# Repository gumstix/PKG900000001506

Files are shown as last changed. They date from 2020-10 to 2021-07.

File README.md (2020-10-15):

# Gumstix Raspberry Pi CM Robo
## PKG900000001506 

**The Gumstix Raspberry Pi CM Robo** carrier board is a slim, computer vision-capable multimedia platform designed with miniature autonomous vehicles in mind.  The dual Raspberry Pi Camera connectors can provide either stereoscopic depth mapping for object avoidance or front- and back-facing cameras for feature identification or manual control.

I2C and UART serial connections, exposed via JST GH-style headers, can be used to connect either to PWM motor controller boards, or to a control MCU.

Instantly upgrade your project with the Gumstix Raspberry Pi CM4 Uprev board and take advantage of the CM4's increased horsepower.  Or go even further with the UprevAI and add a Google Coral TPU for lightning-fast TensorFlow processing.

__Features Include__:
* Power via **USB Type-C Power Delivery**
* Mini-HDMI-out
* DSI touch display connector
* Dual CSI2 camera connectors
* USB Type-A host connection
* 2x WS2812B-MINI RGB LEDs

__Links:__
* [AutoDoc Datasheet][autodoc]
* [Specifications][spec]
* [Store Page][store]
* [Schematics and Layout][hardware]

[thumbnail]: https://d3iwea566ns1n1.cloudfront.net/images/product/cfc476a8175b0227c75bd2853a3e6107ad4b8505.png
[autodoc]: PKG900000001506_AutoDoc.pdf
[spec]: PKG900000001506_SpecSheet.pdf
[store]: https://store.gumstix.com/cm-robo/
[hardware]: hardware/hardware.md
[firmware]: firmware/firmware.md

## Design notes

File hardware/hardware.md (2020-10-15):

# Hardware

[Schematic PDF][pdf]
EAGLE [Schematic][sch] and [Layout][brd]

[pdf]: PKG900000001506.pdf
[brd]: PKG900000001506.brd
[sch]: PKG900000001506.sch

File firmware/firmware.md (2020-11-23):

# Firmware

__Custom Gumstix Ubuntu Server 20.04 images for Rasberry Pi CM4__:

* [Ubuntu Server 20.04](https://gumstix-ubuntu.s3-us-west-2.amazonaws.com/2020-10-18/raspberrypi-cm4/rosbuntu_cm4_i2.img.gz)
* Username: ubuntu
* Password: raspberry

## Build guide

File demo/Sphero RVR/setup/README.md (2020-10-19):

# Demo

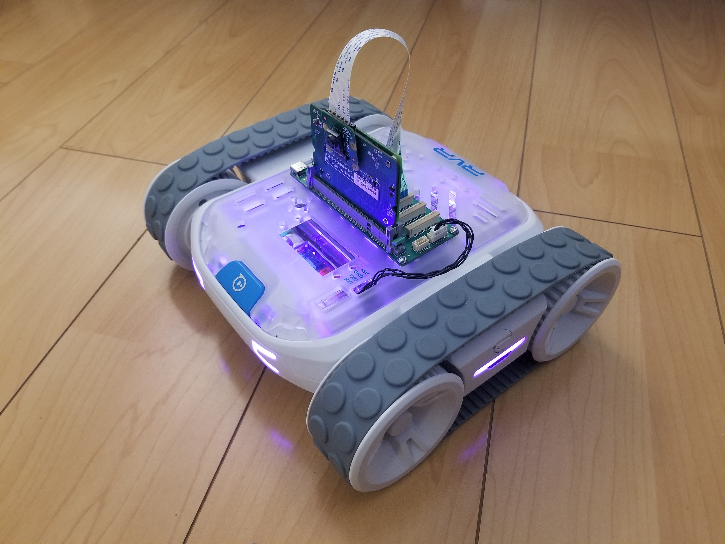
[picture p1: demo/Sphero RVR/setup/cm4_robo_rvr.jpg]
Gumstix Raspberry Pi CM4 Robo (https://youtu.be/AIH_TkKFwOI "Gumstix Raspberry Pi CM4 Robo")


# Demo

v4l2loopback Installation

    git clone https://github.com/umlaeute/v4l2loopback
    cd v4l2loopback
    make && sudo make install && sudo depmod -a

Sphero-sdk Installation

    git clone https://github.com/sphero-inc/sphero-sdk-raspberrypi-python
    cd sphero-sdk-raspberrypi-python
    sudo python3 setup.py install

Map ttyS0 to UART4
* Remove all console references in /boot/firmware/cmdline.txt
* Remove “enable_uart = 1” in /boot/firmware/syscfg.txt
* Add “dtoverlay = uart4” in /boot/firmware/usercfg.txt
* Write to /etc/rc.local:

    ~~~
    #!/bin/bash
    ln -s /dev/ttyAMA1 /dev/ttyS0
    ~~~

*       sudo chmod a+x /etc/rc.local

ROS2 Foxy Installation

    sudo apt update && sudo apt install curl gnupg2 lsb-release
    curl -s https://raw.githubusercontent.com/ros/rosdistro/master/ros.asc | sudo apt-key add –
    sudo sh -c 'echo "deb [arch=$(dpkg --print-architecture)] http://packages.ros.org/ros2/ubuntu $(lsb_release -cs) main" > /etc/apt/sources.list.d/ros2-latest.list'
    sudo apt update
    sudo apt install ros-foxy-ros-base
    echo "source /opt/ros/foxy/setup.sh" >> ~/.bashrc

Remotv installation

    git clone https://github.com/remotv/controller.git remotv
    cd remotv/
    sudo apt install ffmpeg python3-serial python3-dev libgnutls28-dev espeak python3-smbus python3-pip git
    wget https://raw.githubusercontent.com/Yoruio/controller/master/hardware/rvrros.py -O hardware/rvrros.py
    cp controller.sample.conf controller.conf

edit controller.conf (https://github.com/remotv/controller -> ‘Configure the controller’)

Opencv Streamer

    sudo apt-get install libopencv-dev python3-opencv
    sudo apt-get install libgstreamer1.0-0 gstreamer1.0-plugins-base gstreamer1.0-plugins-good \
    gstreamer1.0-plugins-bad gstreamer1.0-plugins-ugly gstreamer1.0-libav gstreamer1.0-doc \
    gstreamer1.0-tools gstreamer1.0-x gstreamer1.0-alsa gstreamer1.0-gl gstreamer1.0-gtk3 gstreamer1.0- \
    qt5 gstreamer1.0-pulseaudio
    git clone https://github.com/yoruio/coral-streamer

ROS RVR Node installation

    git clone https://github.com/Yoruio/ros2-rvr-node (run synchronous.py)

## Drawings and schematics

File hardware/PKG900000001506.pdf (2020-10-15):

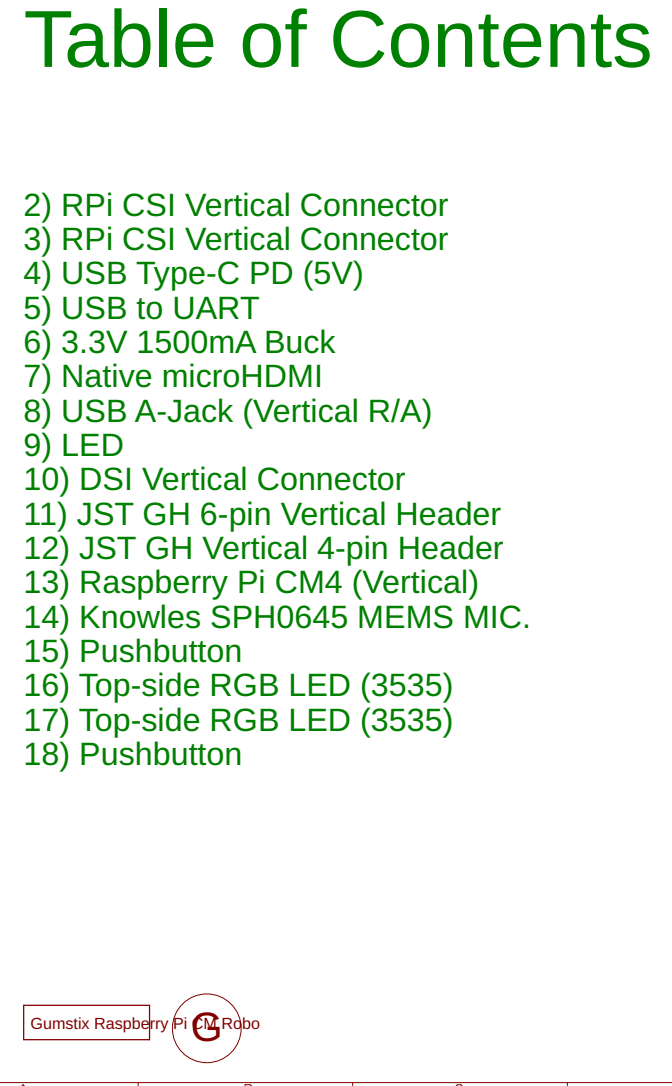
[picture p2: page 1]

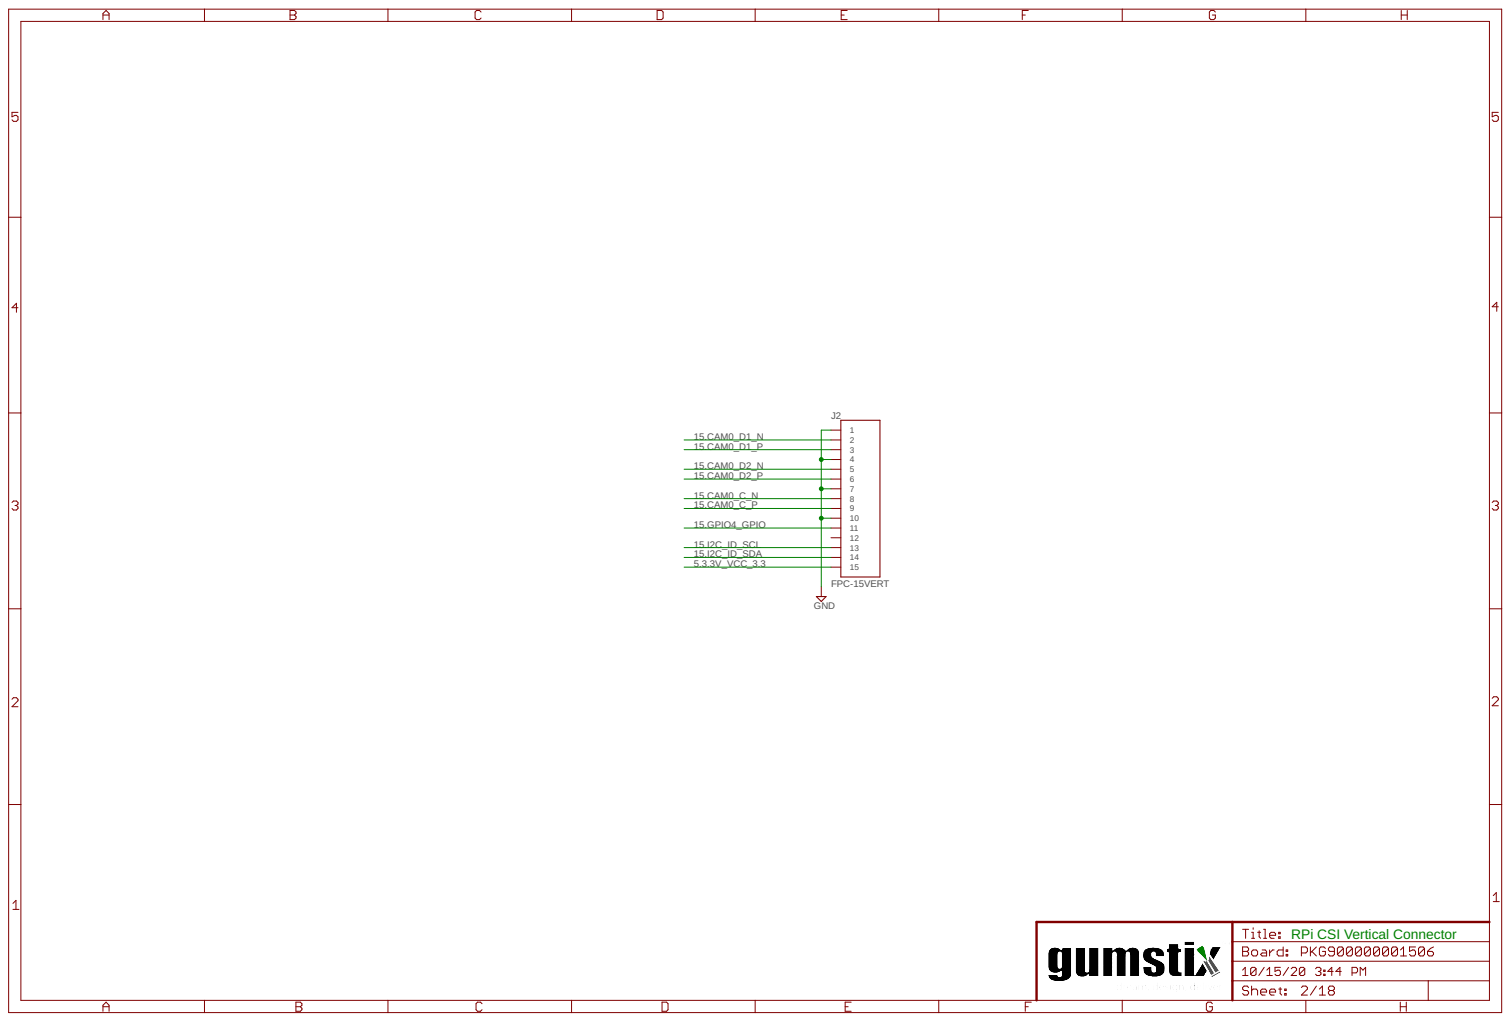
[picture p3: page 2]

RPi CSI Vertical Connector

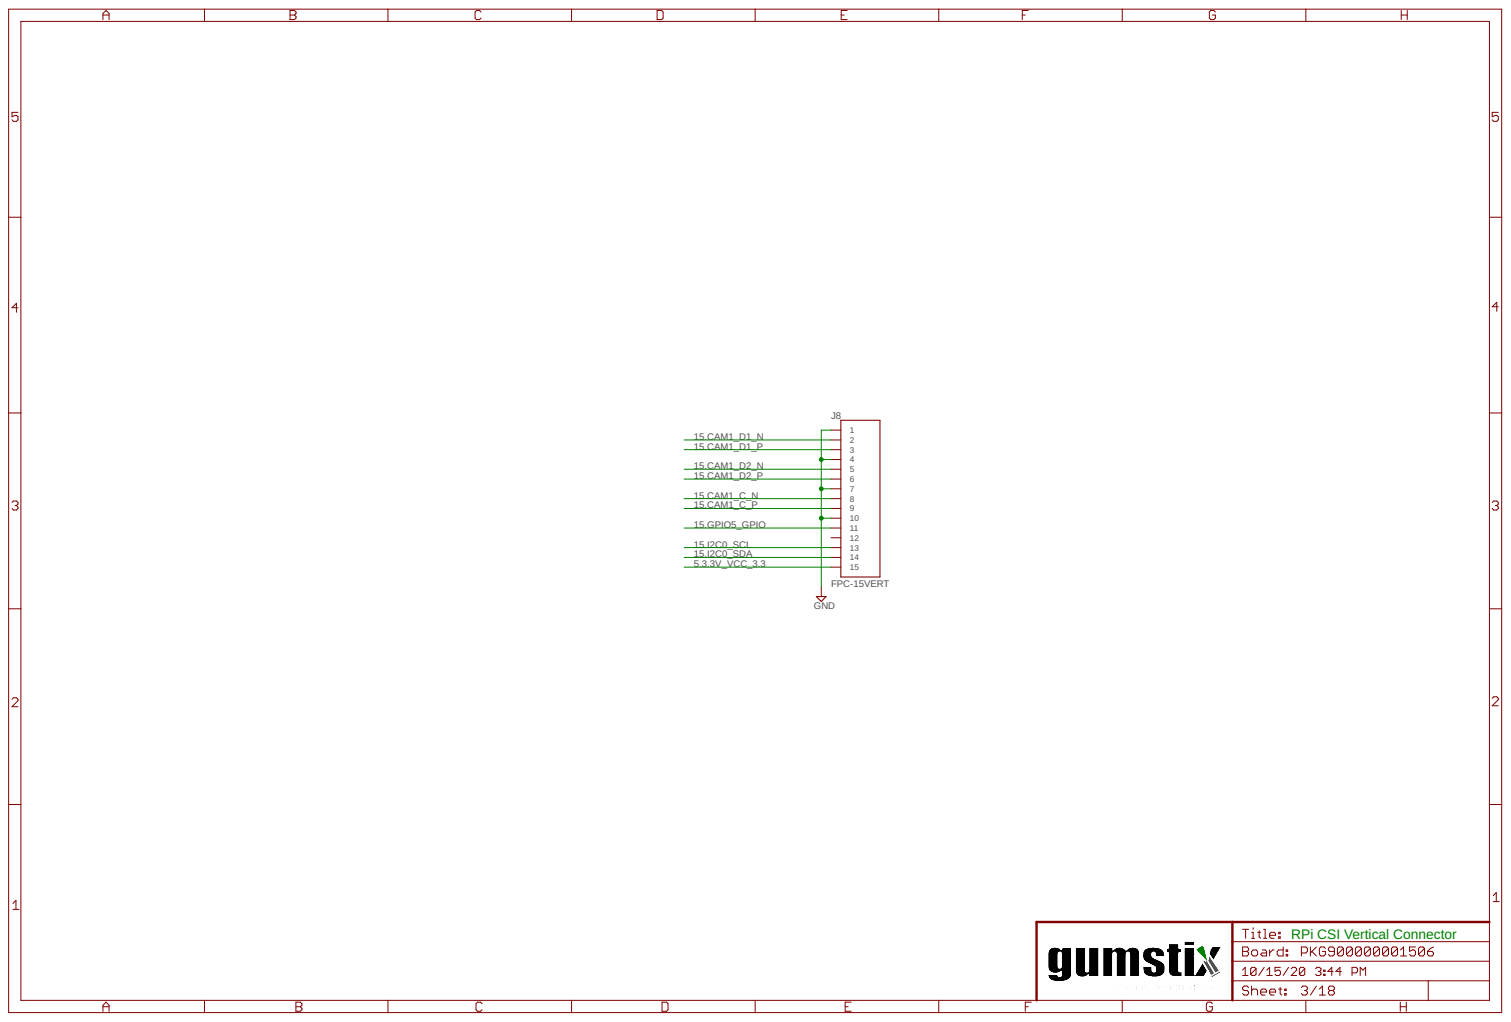
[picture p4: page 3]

RPi CSI Vertical Connector

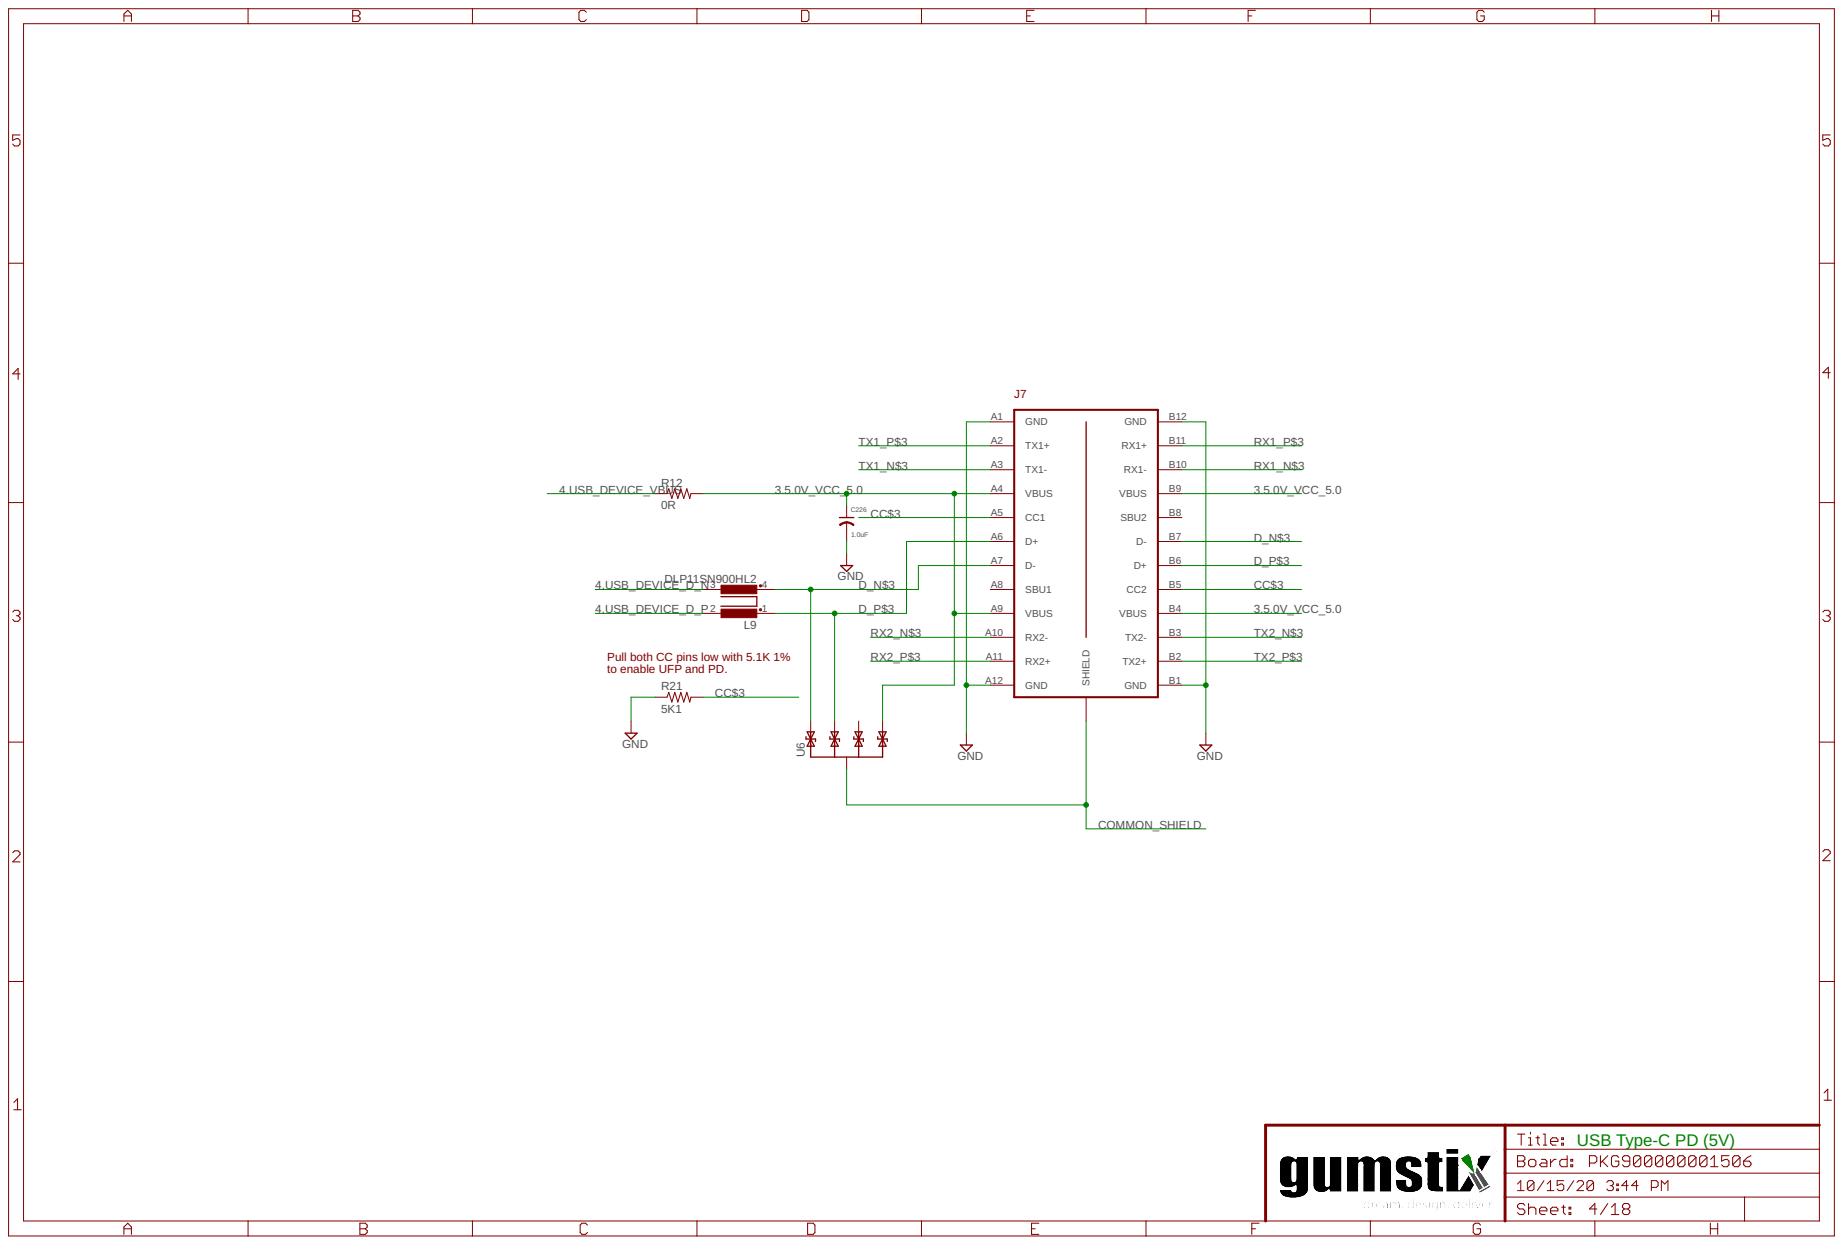
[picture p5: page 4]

Pull both CC pins low with 5.1K 1%
to enable UFP and PD.

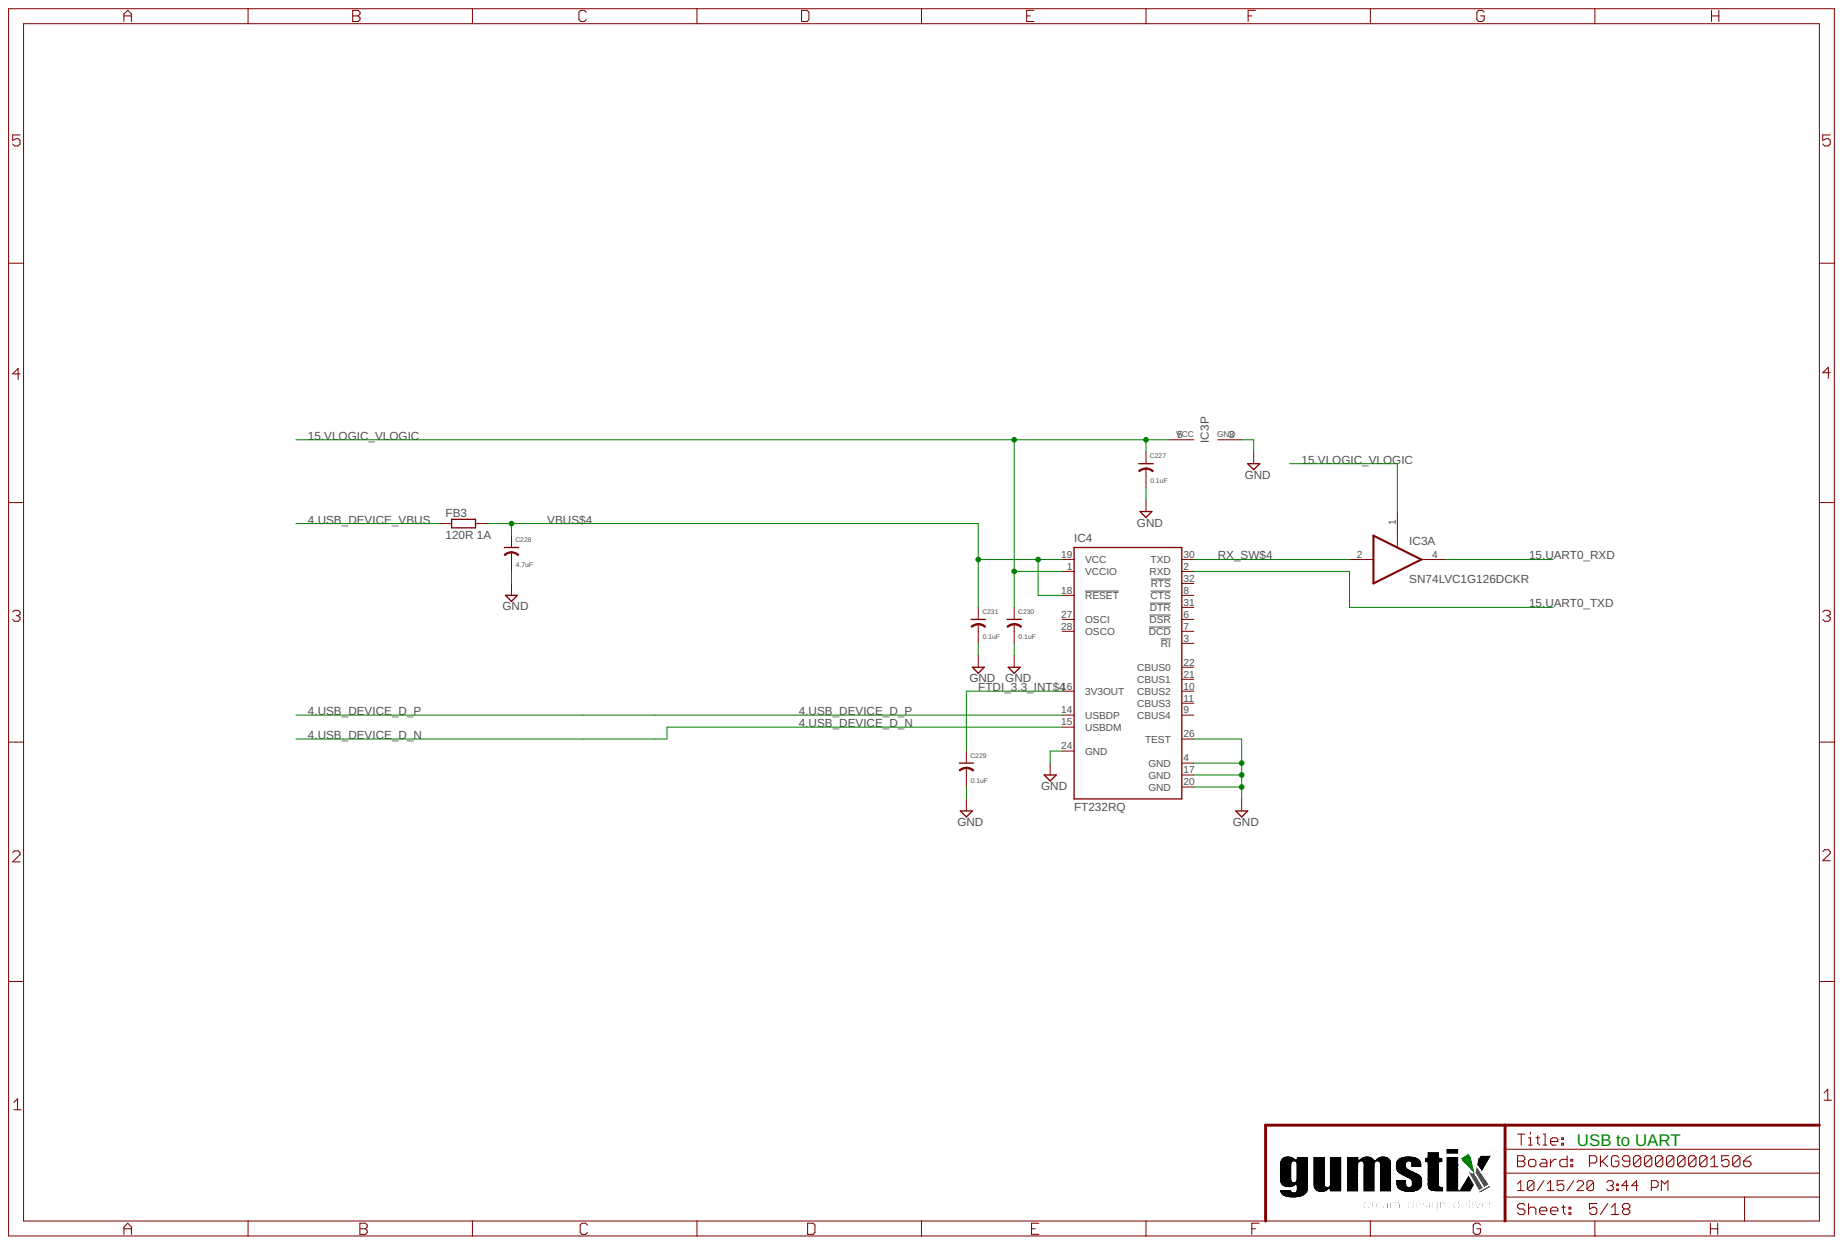
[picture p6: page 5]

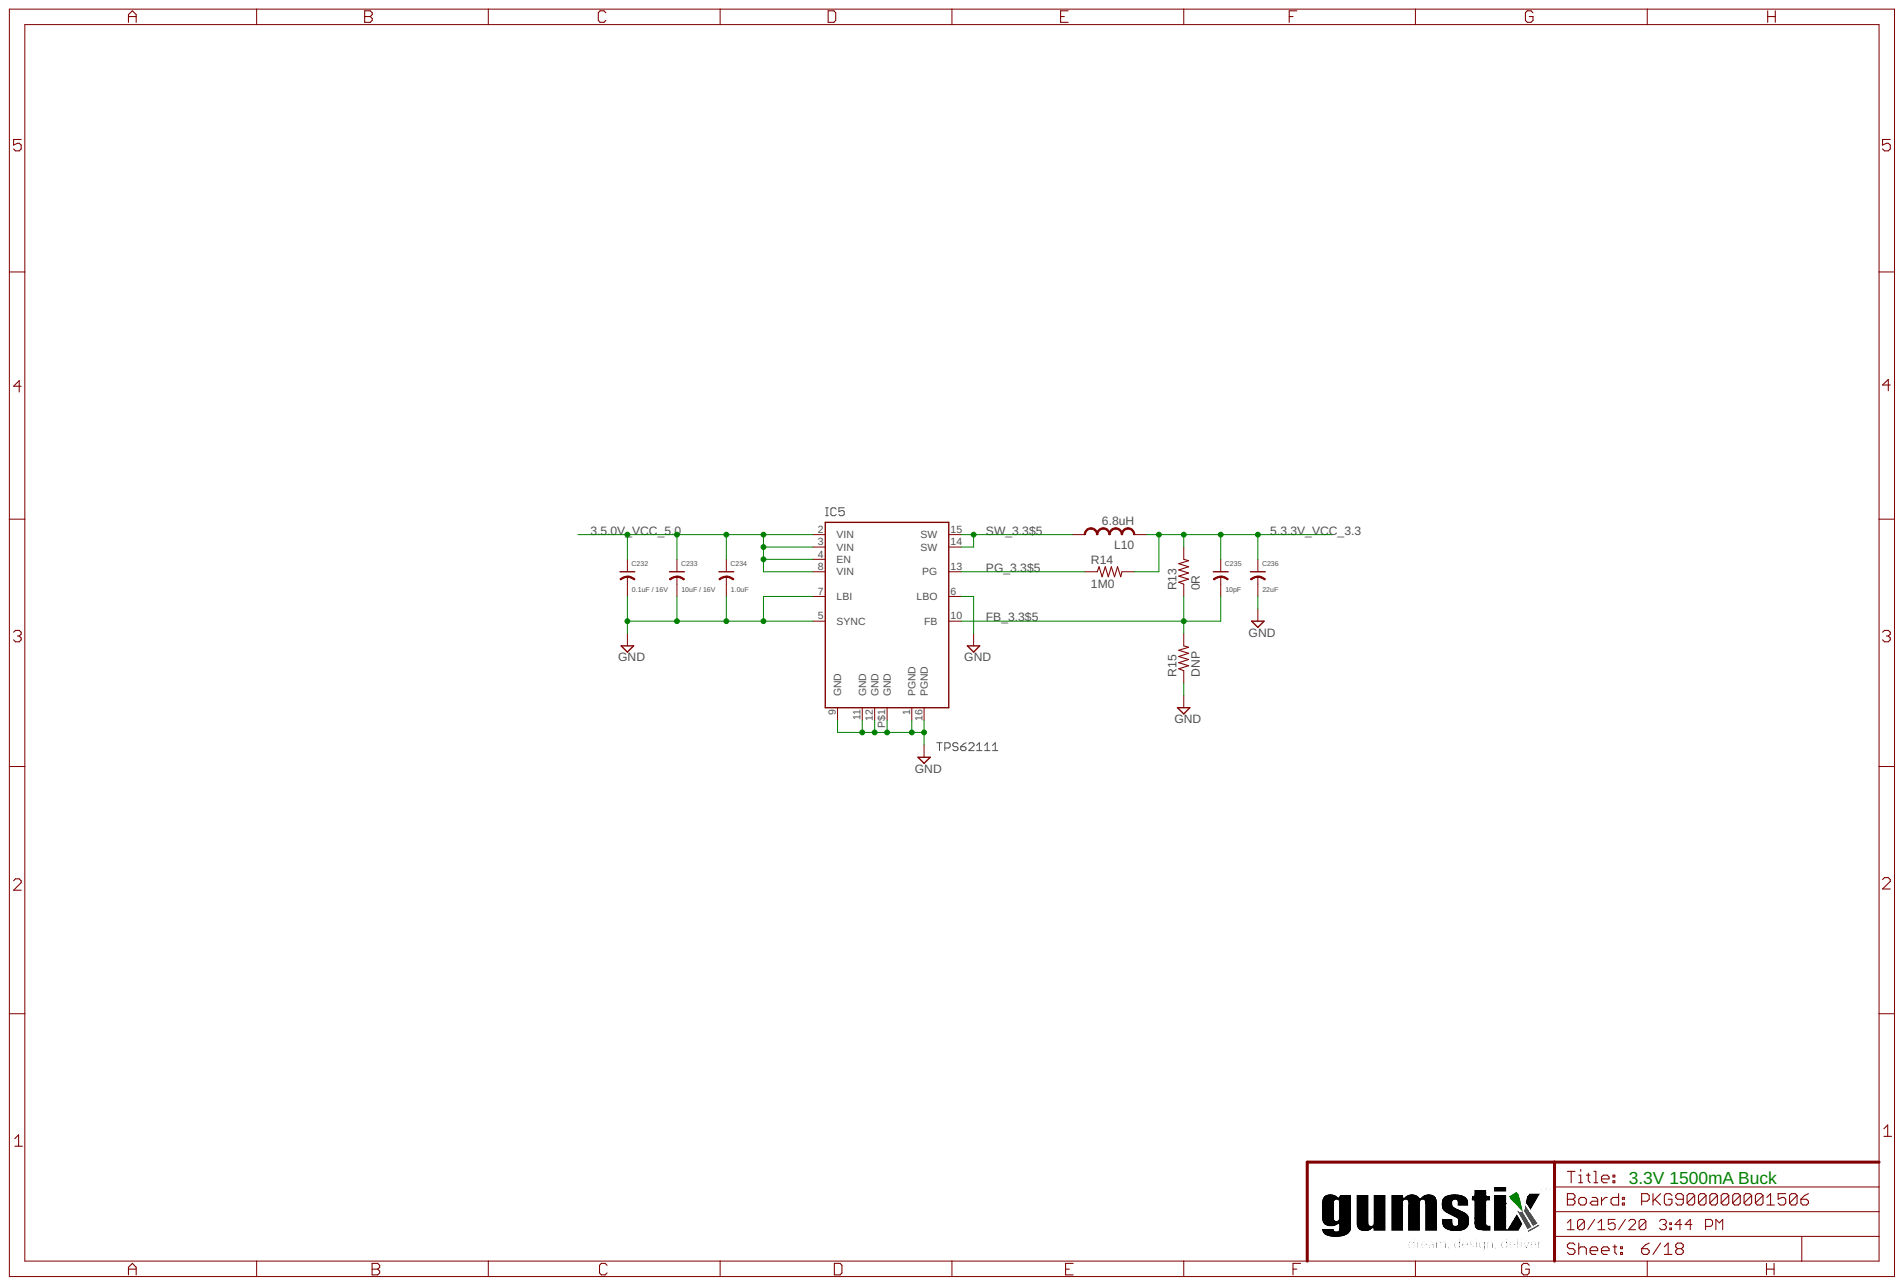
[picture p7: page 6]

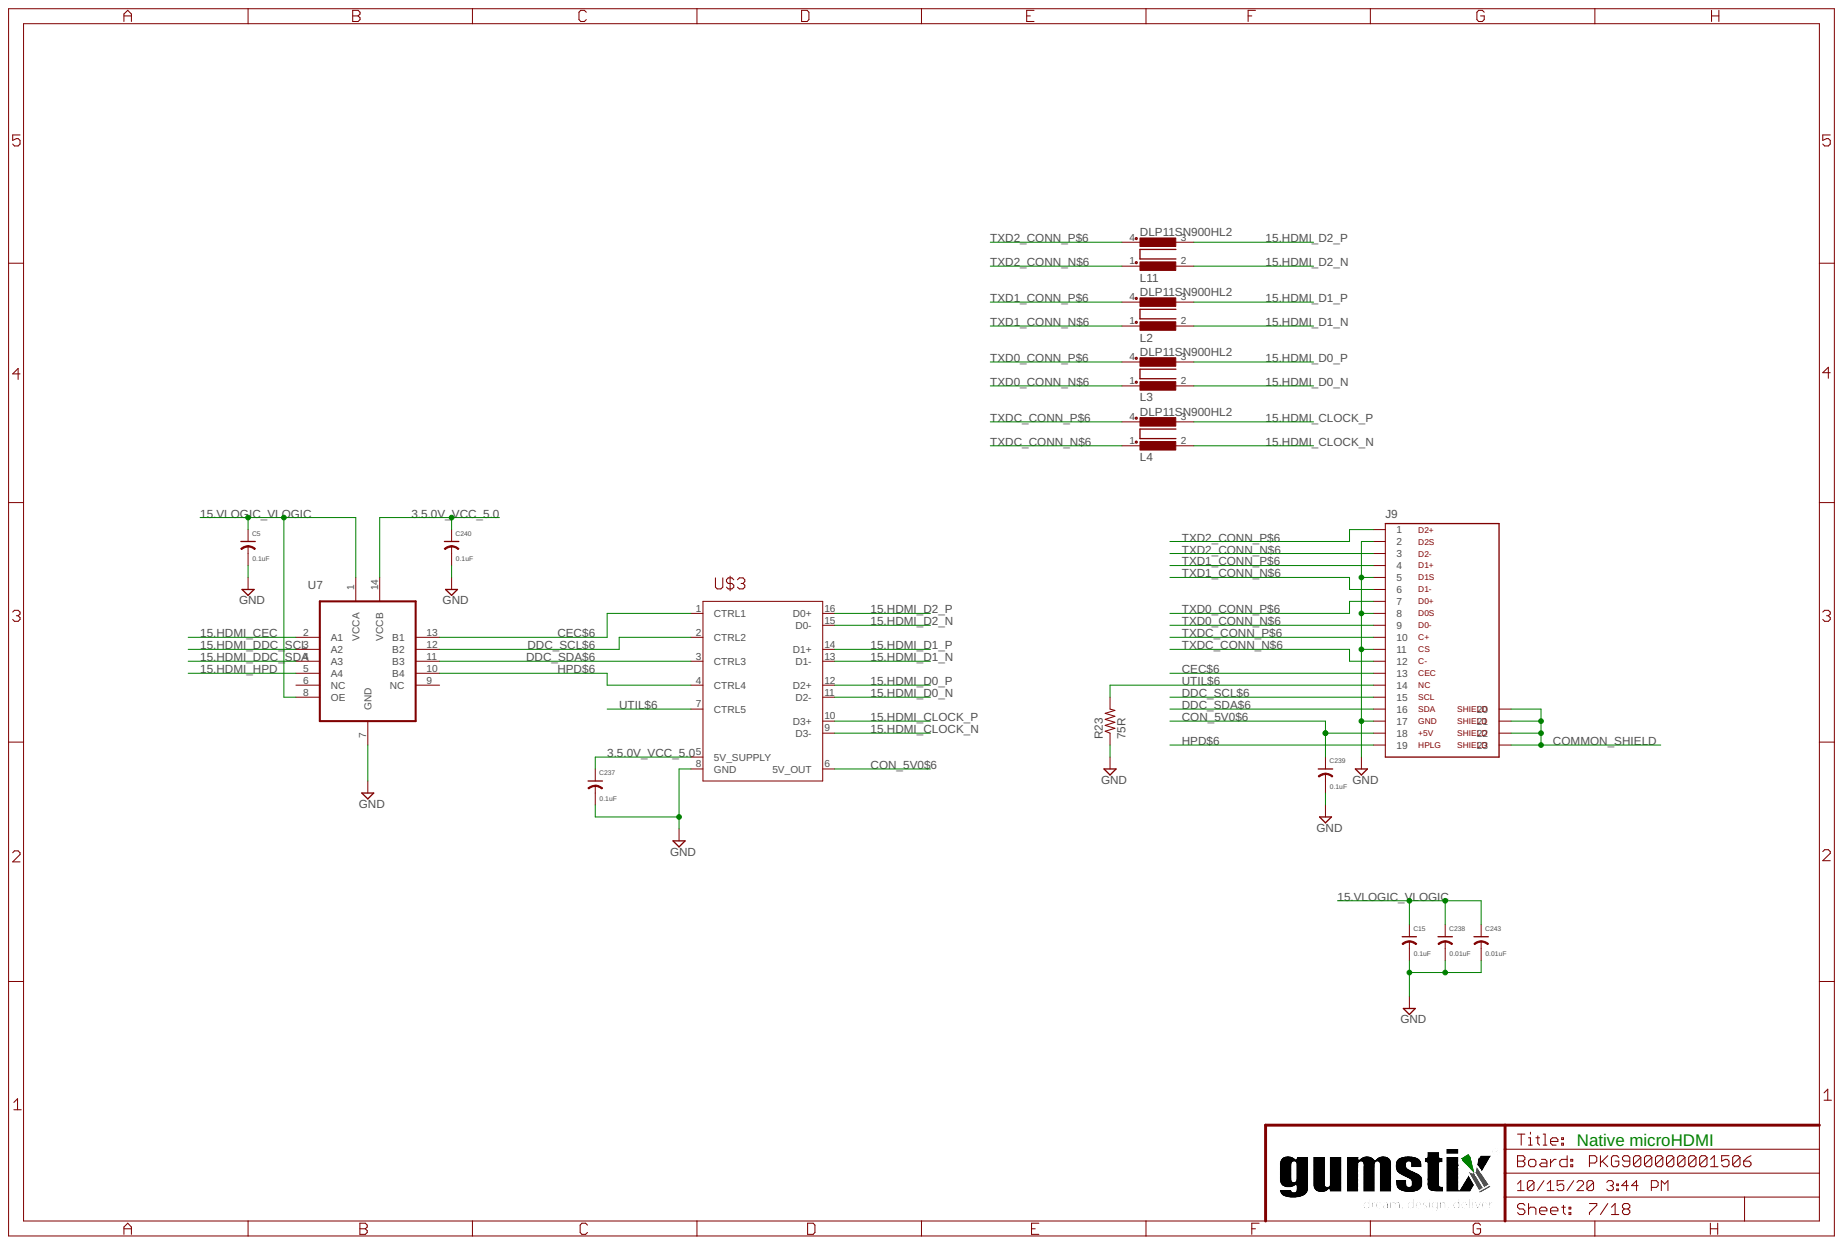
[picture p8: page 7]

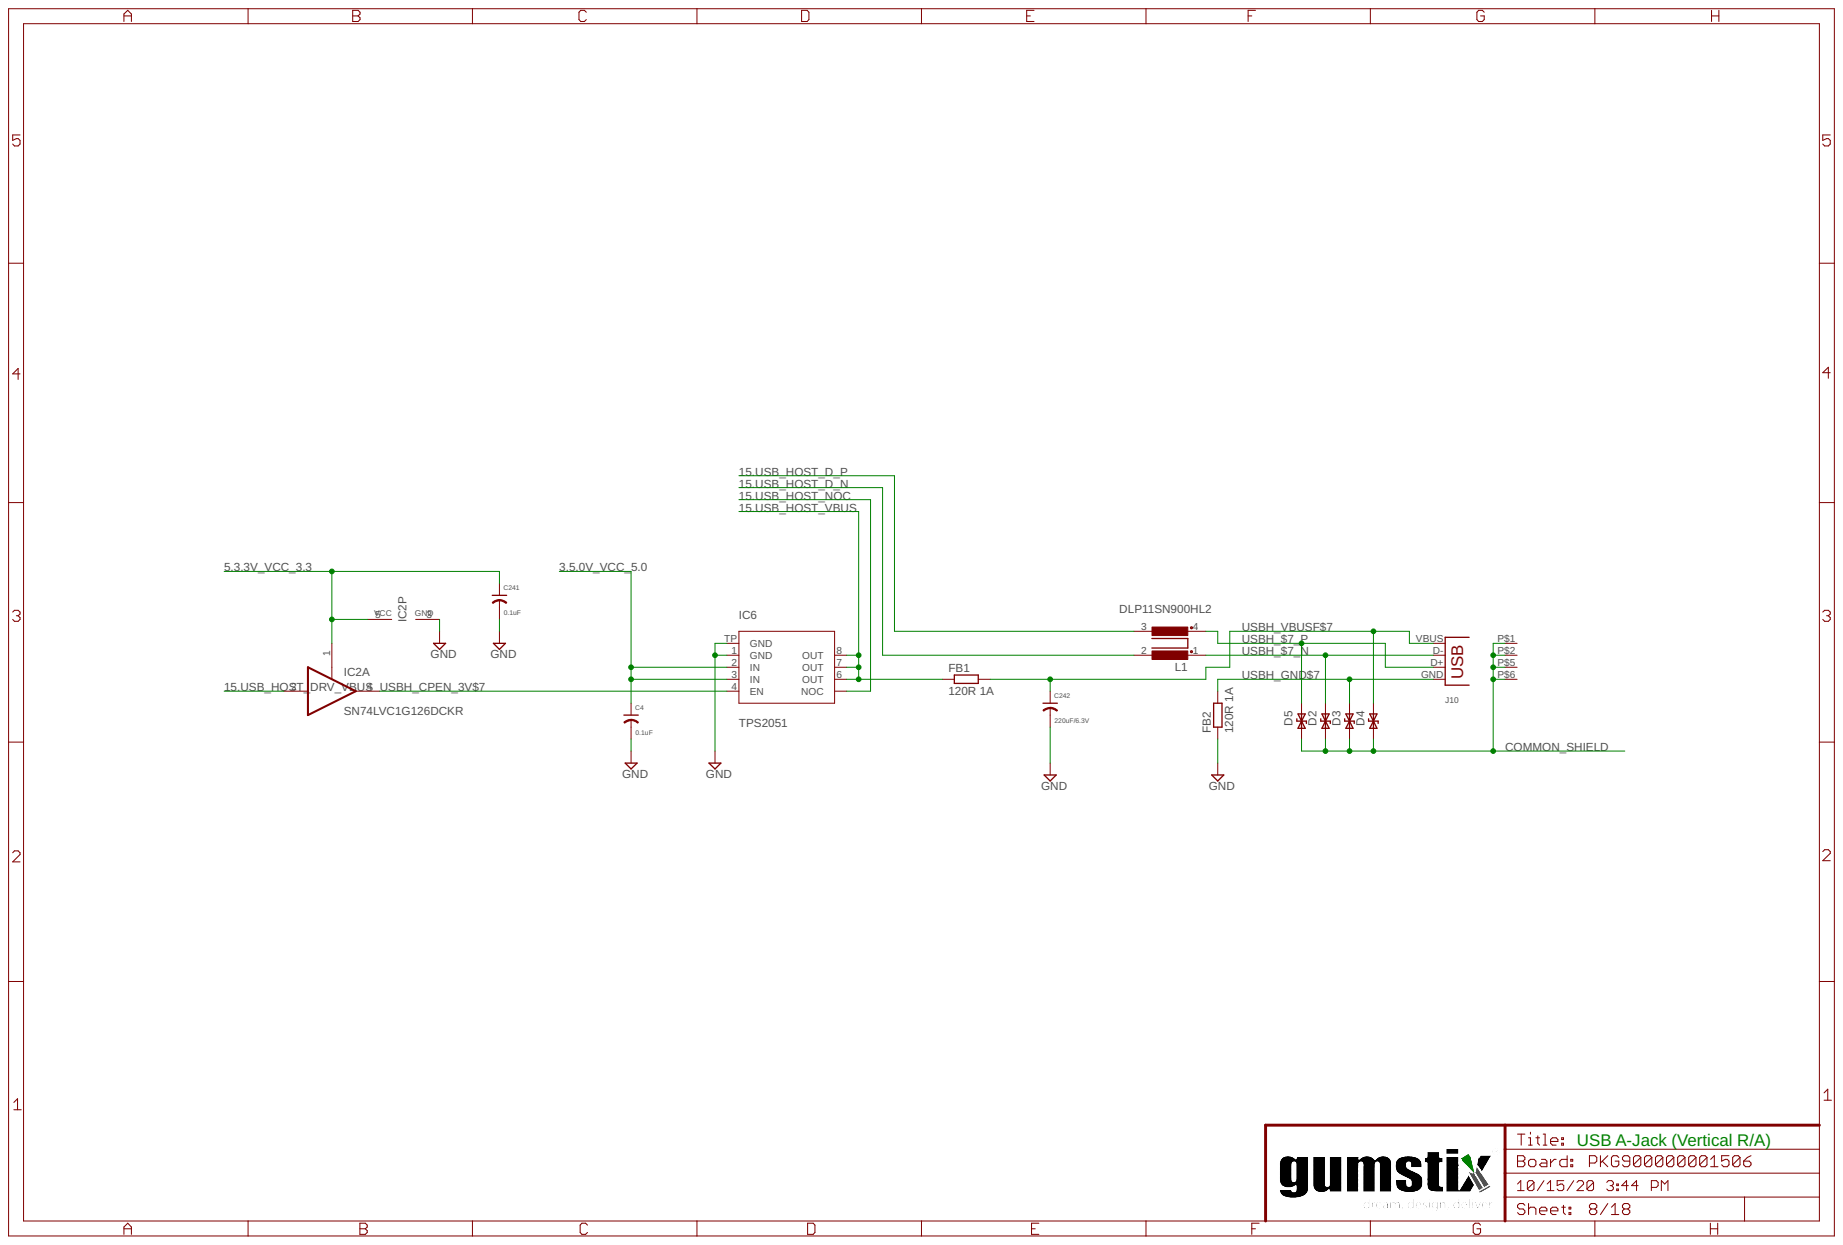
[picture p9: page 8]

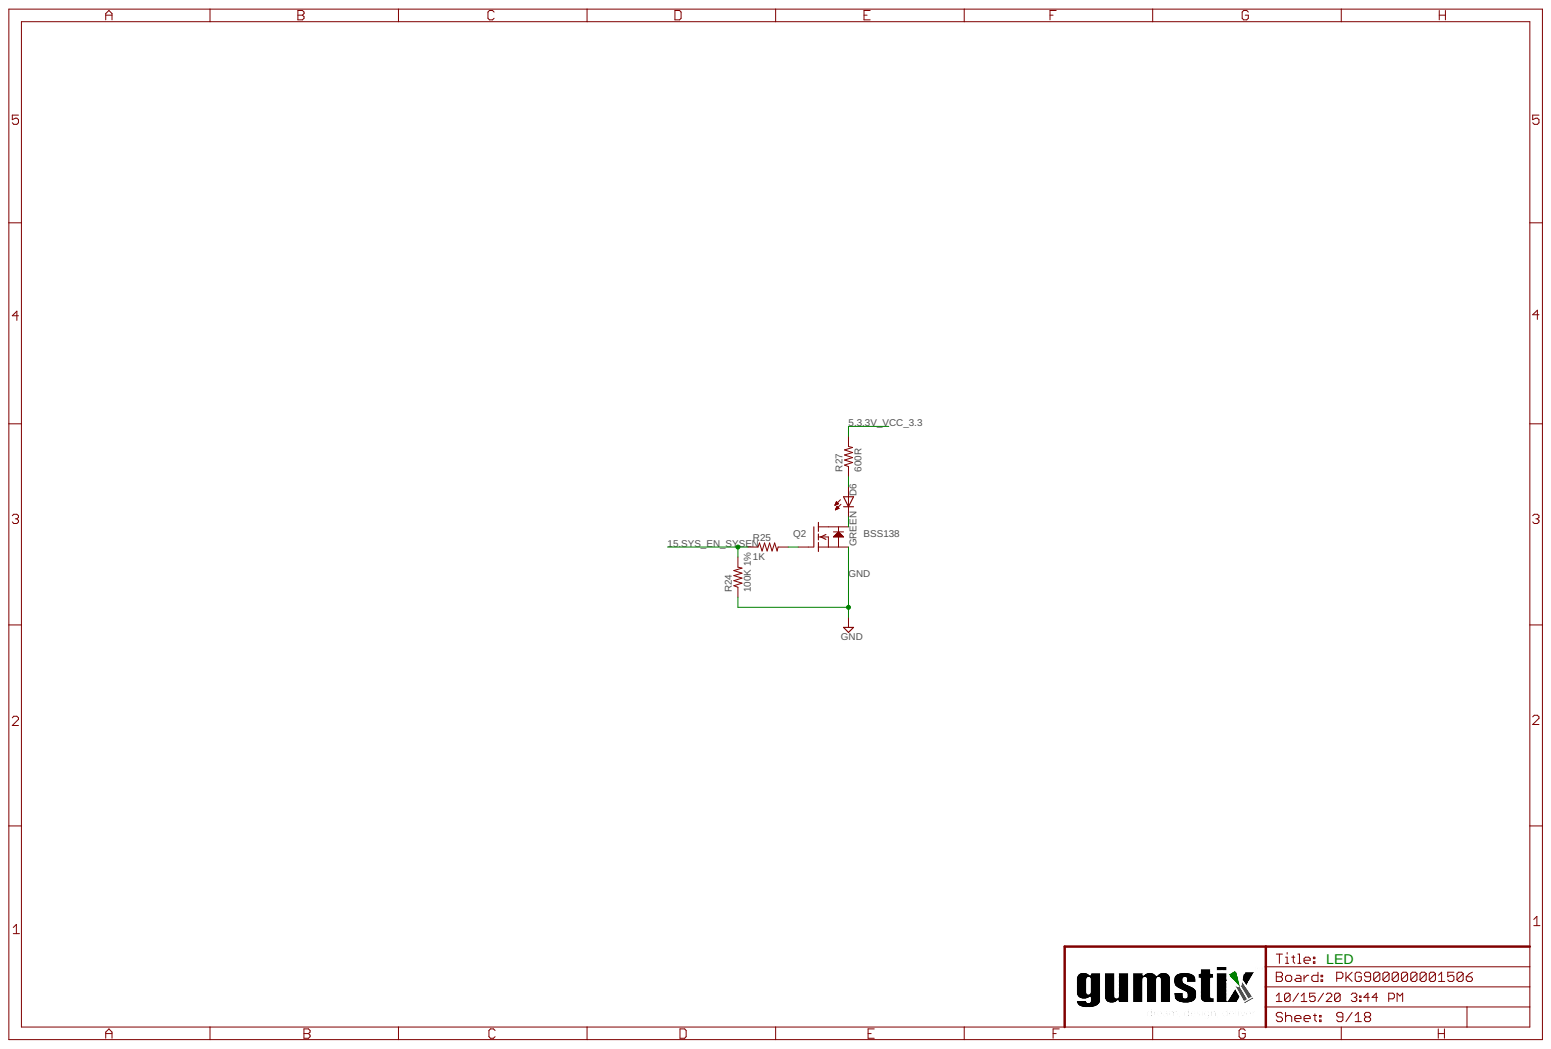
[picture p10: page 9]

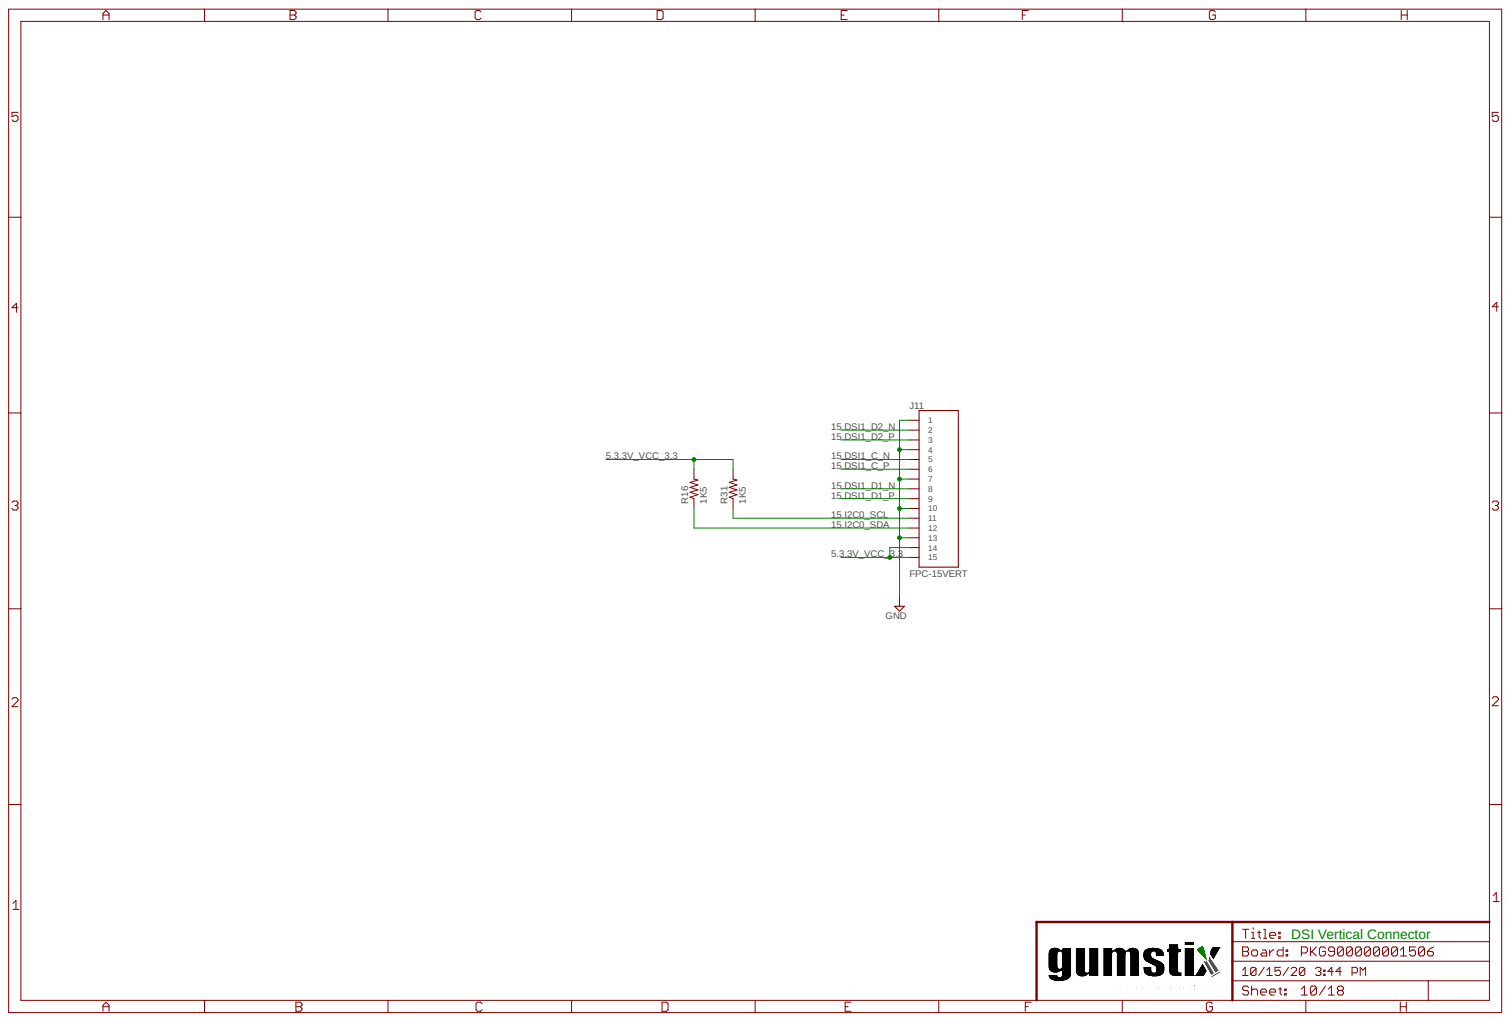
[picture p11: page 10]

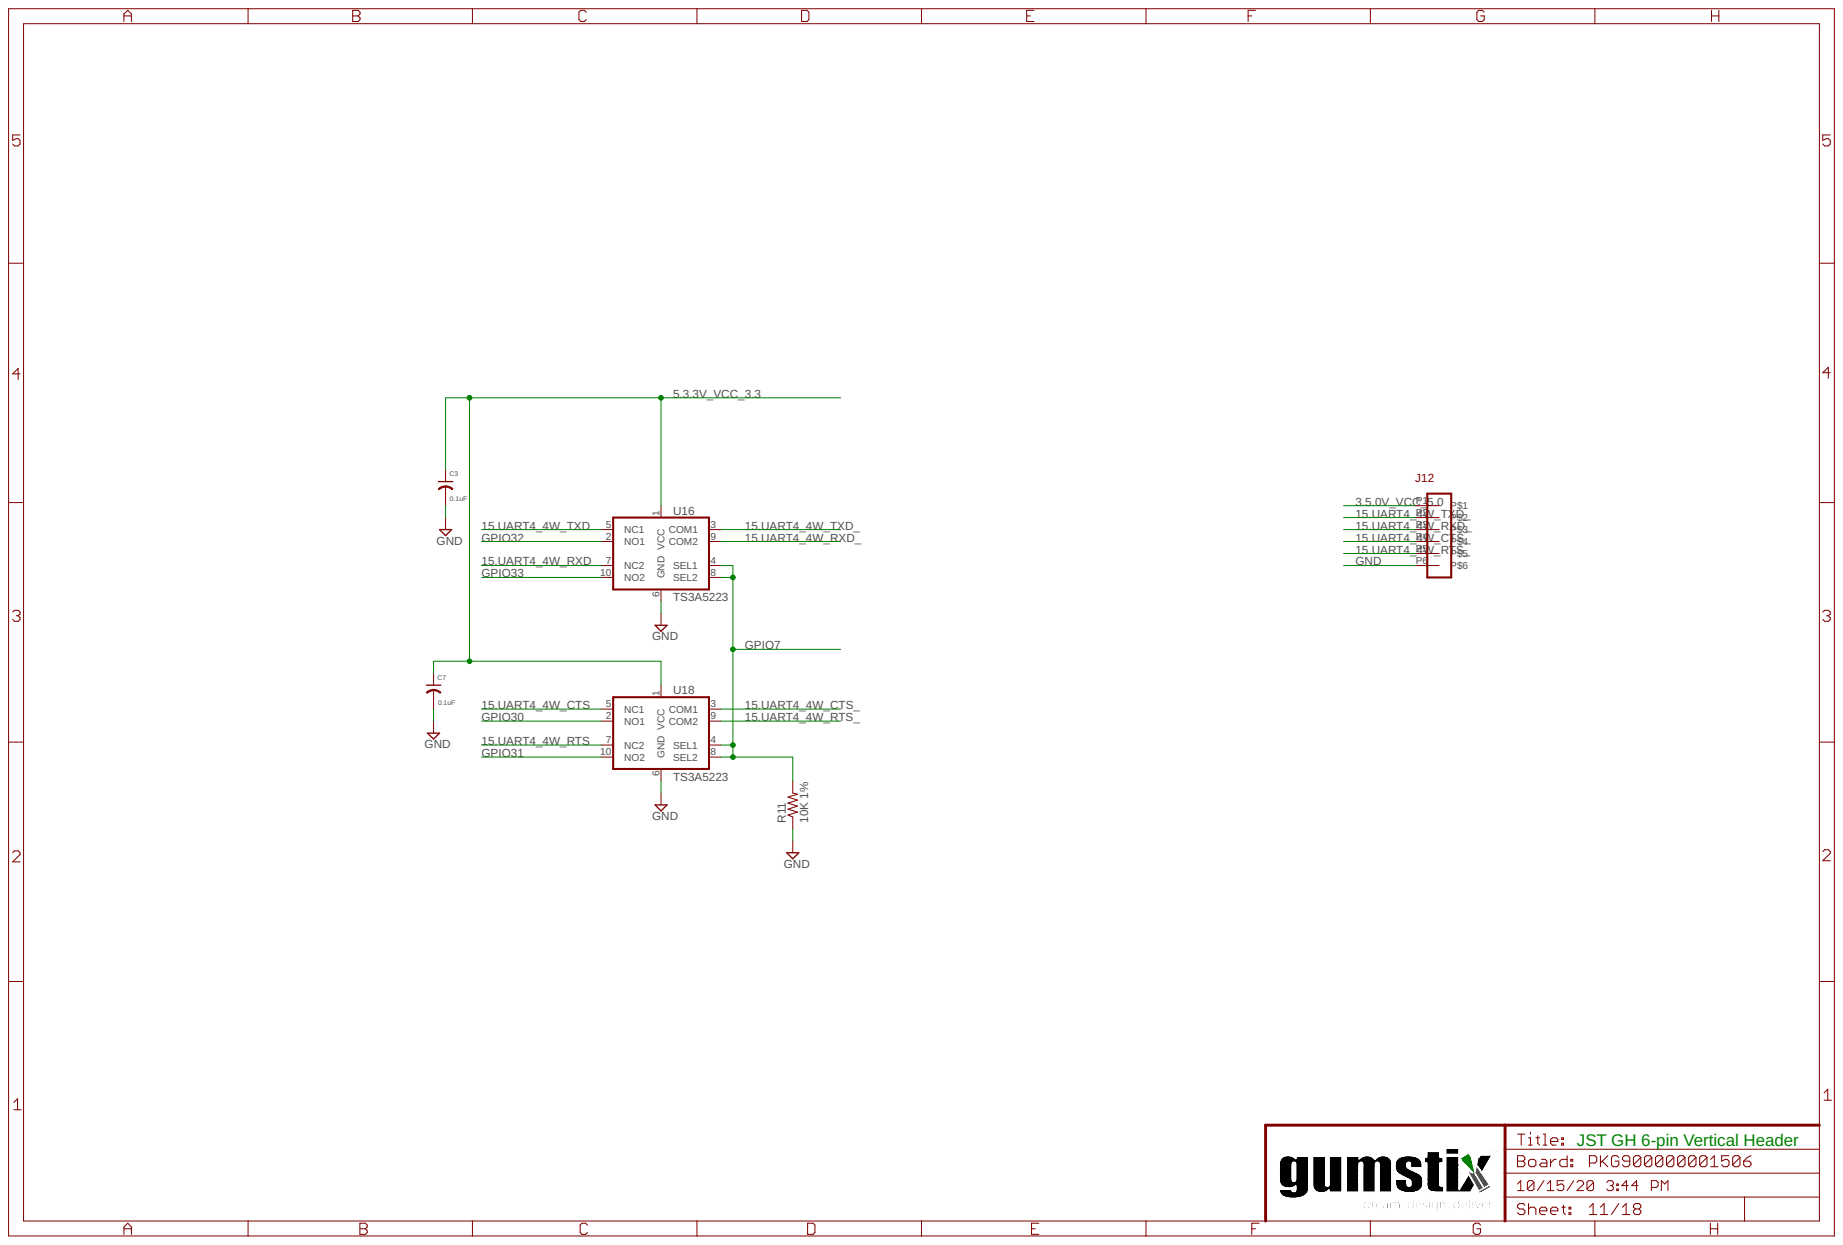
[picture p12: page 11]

JST GH 6-pin Vertical Header

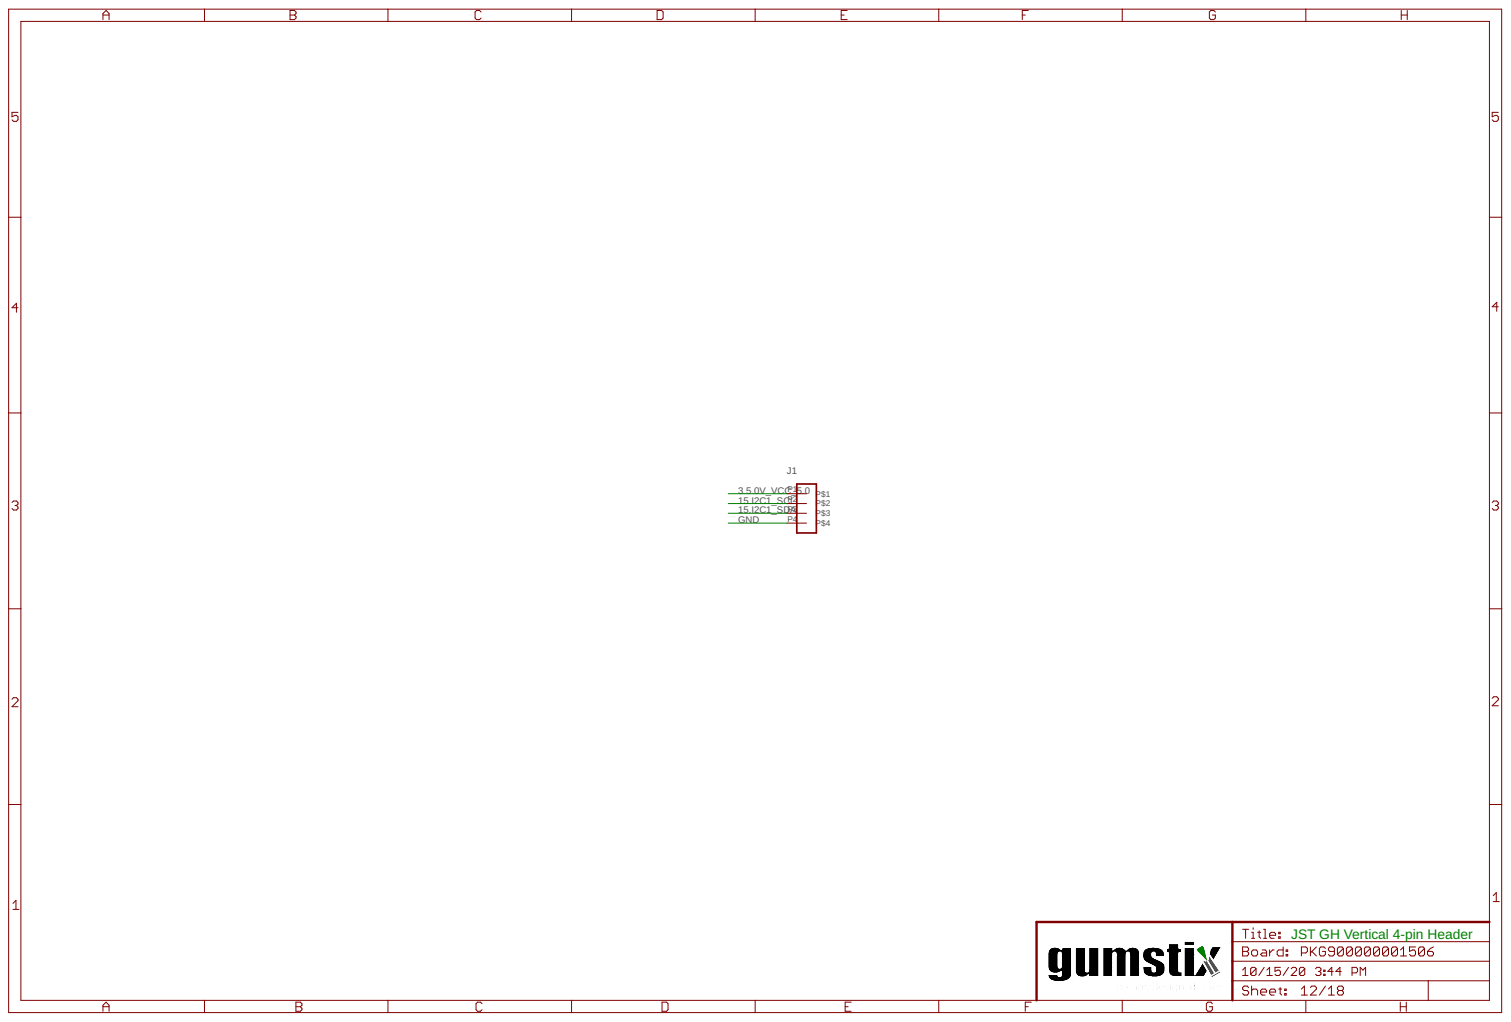
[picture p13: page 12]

JST GH Vertical 4-pin Header


GND GND GND GND GND GND GND GND GND

GND GND

15.DSI1_C_N
GND GND GND GND
15.DSI1_D4_P
15.DSI1_D4_N

15.UART0_RXD

GPIOs 28-43 do not connect to BCM2711 They are connected to a TCA6416A GPIO expander Therefore they can only be used as GPIOs




Top-side RGB LED (3535)


Top-side RGB LED (3535)


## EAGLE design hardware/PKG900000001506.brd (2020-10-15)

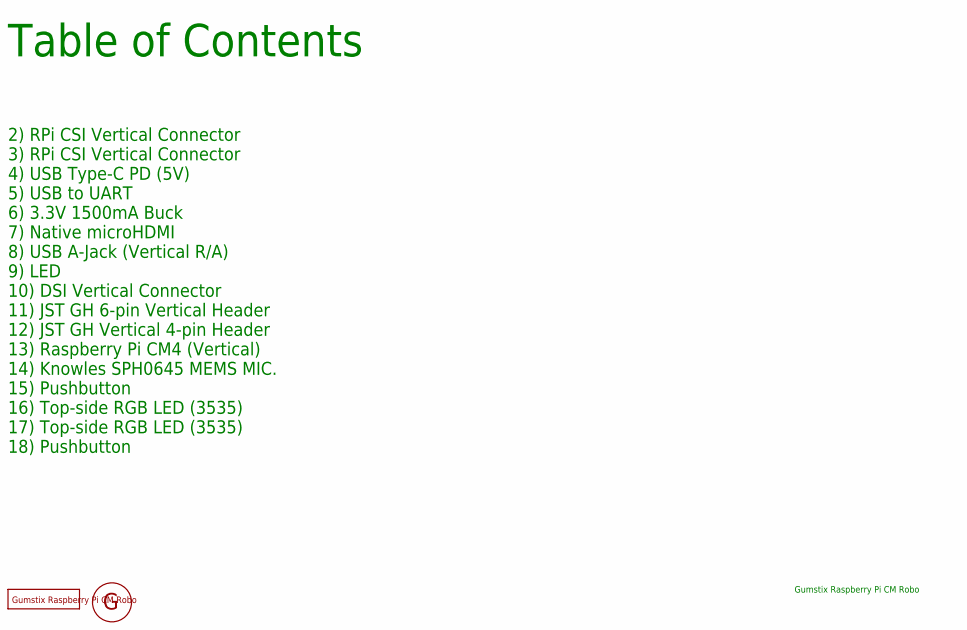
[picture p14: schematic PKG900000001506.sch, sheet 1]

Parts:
FD1, FD2, FD3, FD4, FD5, FD6, FD7, FD8: DNP; FIDUCIAL
U$4: DNP; GEPPETTO_LABEL
U$5: DNP; GEPPETTO_LOGO_SILK10

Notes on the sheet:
Table of Contents
Gumstix Raspberry Pi CM Robo
2) RPi CSI Vertical Connector
3) RPi CSI Vertical Connector
4) USB Type-C PD (5V)
5) USB to UART
6) 3.3V 1500mA Buck
7) Native microHDMI
8) USB A-Jack (Vertical R/A)
9) LED
10) DSI Vertical Connector
11) JST GH 6-pin Vertical Header
12) JST GH Vertical 4-pin Header
13) Raspberry Pi CM4 (Vertical)
14) Knowles SPH0645 MEMS MIC.
15) Pushbutton
16) Top-side RGB LED (3535)
17) Top-side RGB LED (3535)
18) Pushbutton

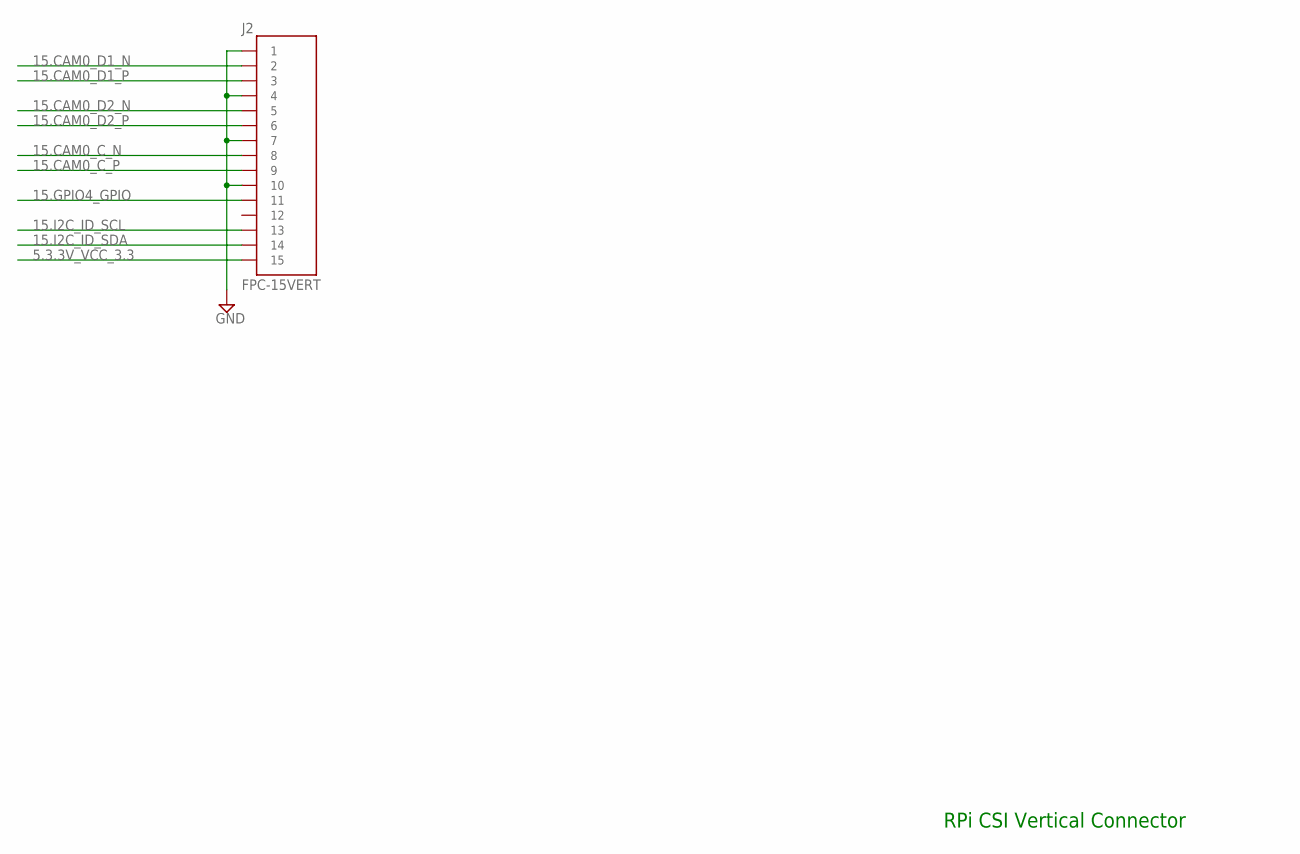
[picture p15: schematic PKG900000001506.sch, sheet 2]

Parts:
J2: FPC-15VERT; 1-1734248-5

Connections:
5.3.3V_VCC_3.3: J2.1_15 (15); also elsewhere on the board
15.CAM0_C_N: J2.1_8 (8); also elsewhere on the board
15.CAM0_C_P: J2.1_9 (9); also elsewhere on the board
15.CAM0_D1_N: J2.1_2 (2); also elsewhere on the board
15.CAM0_D1_P: J2.1_3 (3); also elsewhere on the board
15.CAM0_D2_N: J2.1_5 (5); also elsewhere on the board
15.CAM0_D2_P: J2.1_6 (6); also elsewhere on the board
15.GPIO4_GPIO: J2.1_11 (11); also elsewhere on the board
15.I2C_ID_SCL: J2.1_13 (13); also elsewhere on the board
15.I2C_ID_SDA: J2.1_14 (14); also elsewhere on the board
GND: J2.1_1 (1), J2.1_4 (4), J2.1_7 (7), J2.1_10 (10); also elsewhere on the board

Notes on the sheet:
RPi CSI Vertical Connector

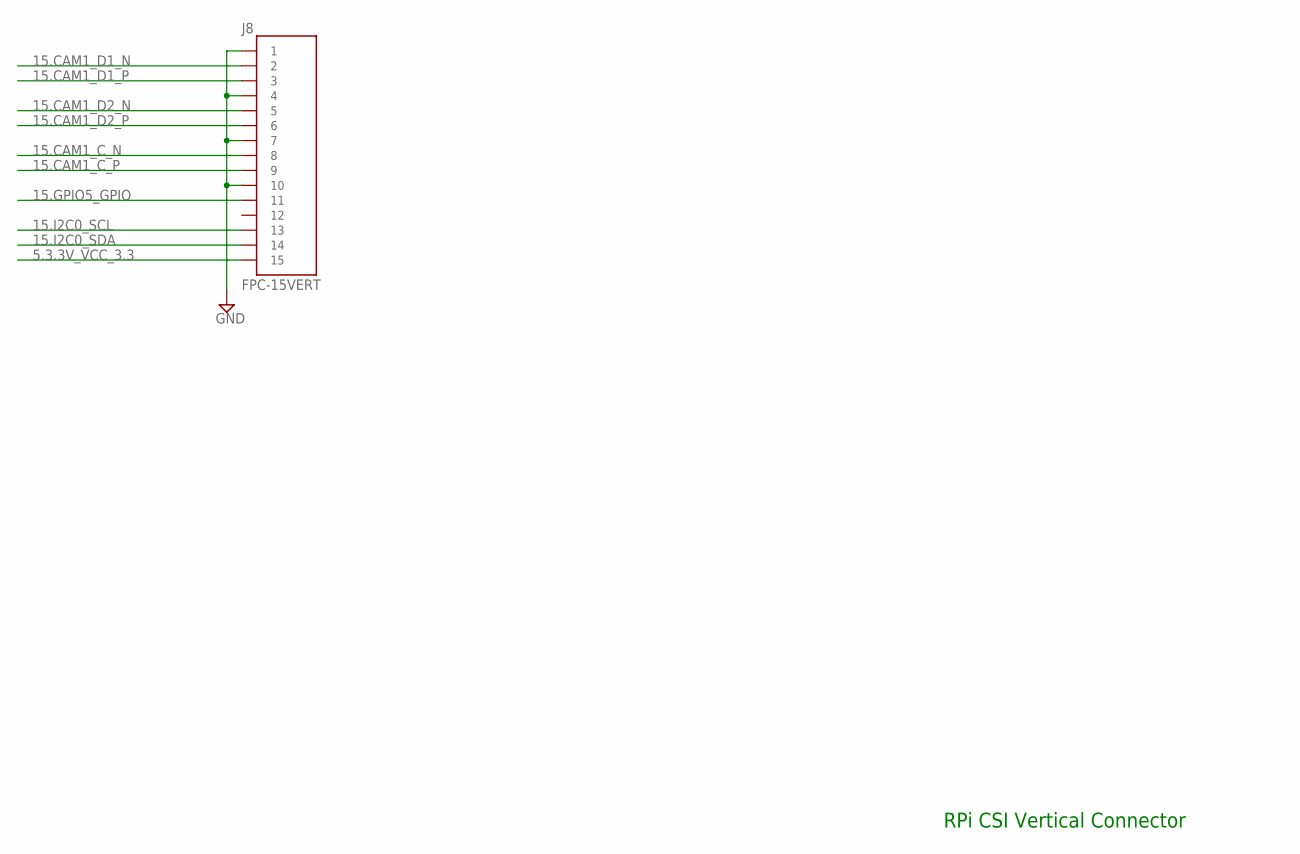
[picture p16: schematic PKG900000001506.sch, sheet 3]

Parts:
J8: FPC-15VERT; 1-1734248-5

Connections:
5.3.3V_VCC_3.3: J8.1_15 (15); also elsewhere on the board
15.CAM1_C_N: J8.1_8 (8); also elsewhere on the board
15.CAM1_C_P: J8.1_9 (9); also elsewhere on the board
15.CAM1_D1_N: J8.1_2 (2); also elsewhere on the board
15.CAM1_D1_P: J8.1_3 (3); also elsewhere on the board
15.CAM1_D2_N: J8.1_5 (5); also elsewhere on the board
15.CAM1_D2_P: J8.1_6 (6); also elsewhere on the board
15.GPIO5_GPIO: J8.1_11 (11); also elsewhere on the board
15.I2C0_SCL: J8.1_13 (13); also elsewhere on the board
15.I2C0_SDA: J8.1_14 (14); also elsewhere on the board
GND: J8.1_1 (1), J8.1_4 (4), J8.1_7 (7), J8.1_10 (10); also elsewhere on the board

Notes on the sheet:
RPi CSI Vertical Connector

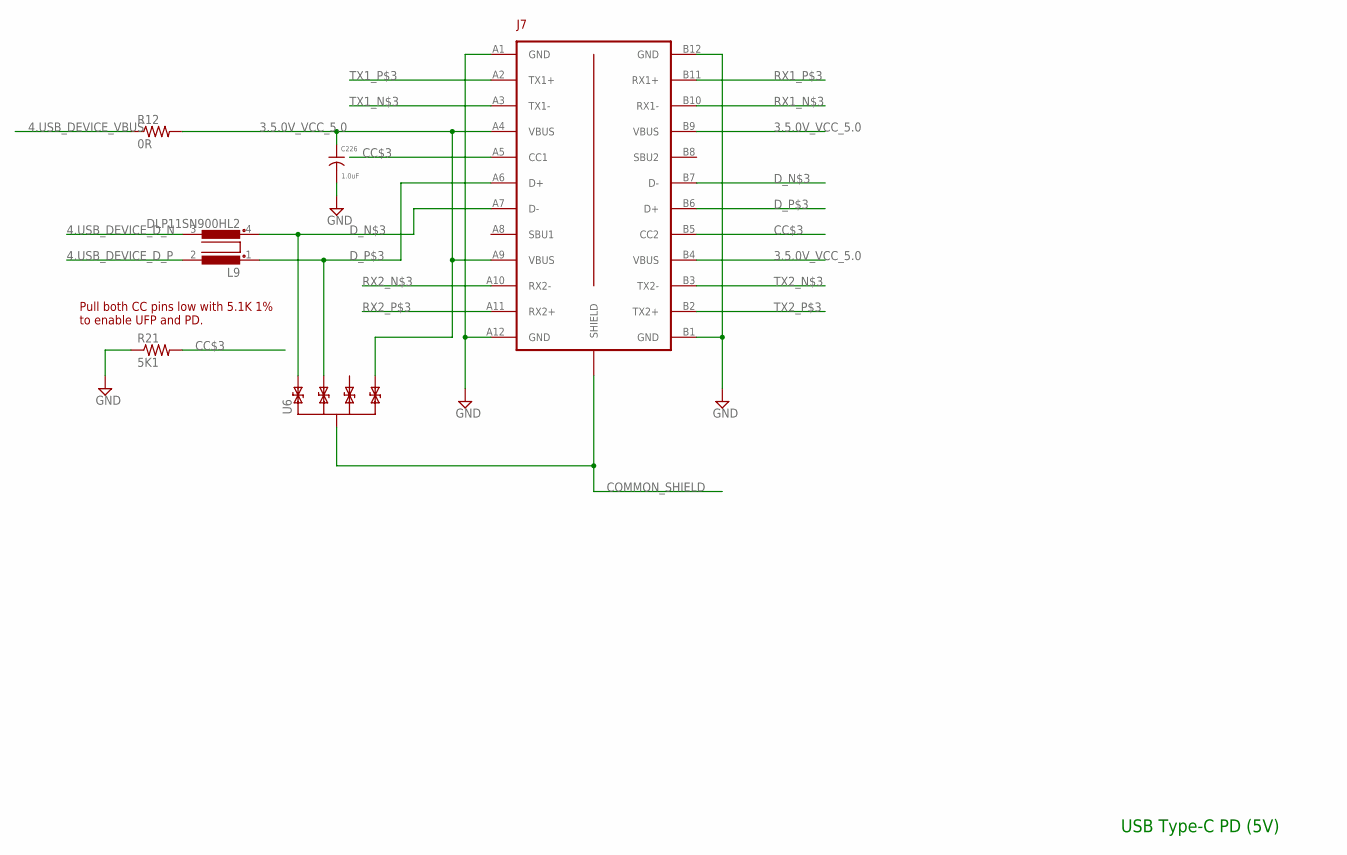
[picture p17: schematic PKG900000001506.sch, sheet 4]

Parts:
C226: 1.0uF; 0402
J7: USB-TYPE-C; USB-TYPE-C-SMT
L9: DLP11SN900HL2; 0504-DLP11S
R12: 0R; 0201
R21: 5K1; 0201
U6: TPD4E02B0410-USON; UFDFN-10

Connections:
3.5.0V_VCC_5.0: C226.1, J7.A4 (VBUS), J7.A9 (VBUS), J7.B4 (VBUS), J7.B9 (VBUS), R12.2, U6.5 (P4), U6.6 (P4); also elsewhere on the board
4.USB_DEVICE_D_N: L9.3; also elsewhere on the board
4.USB_DEVICE_D_P: L9.2; also elsewhere on the board
4.USB_DEVICE_VBUS: R12.1; also elsewhere on the board
CC$3: J7.A5 (CC1), J7.B5 (CC2), R21.2
COMMON_SHIELD: J7.P$1 (SHIELD), J7.P$2 (SHIELD), J7.P$3 (SHIELD), J7.P$4 (SHIELD), U6.3 (SHIELD), U6.8 (SHIELD); also elsewhere on the board
D_N$3: J7.A7 (D-), J7.B7 (D-), L9.4, U6.1, U6.10 (P1)
D_P$3: J7.A6 (D+), J7.B6 (D+), L9.1, U6.2, U6.9 (P2)
GND: C226.2, J7.A1 (GND), J7.A12 (GND), J7.B1 (GND), J7.B12 (GND), R21.1; also elsewhere on the board
RX1_N$3: J7.B10 (RX1-)
RX1_P$3: J7.B11 (RX1+)
RX2_N$3: J7.A10 (RX2-)
RX2_P$3: J7.A11 (RX2+)
TX1_N$3: J7.A3 (TX1-)
TX1_P$3: J7.A2 (TX1+)
TX2_N$3: J7.B3 (TX2-)
TX2_P$3: J7.B2 (TX2+)

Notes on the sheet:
USB Type-C PD (5V)
Pull both CC pins low with 5.1K 1% to enable UFP and PD.

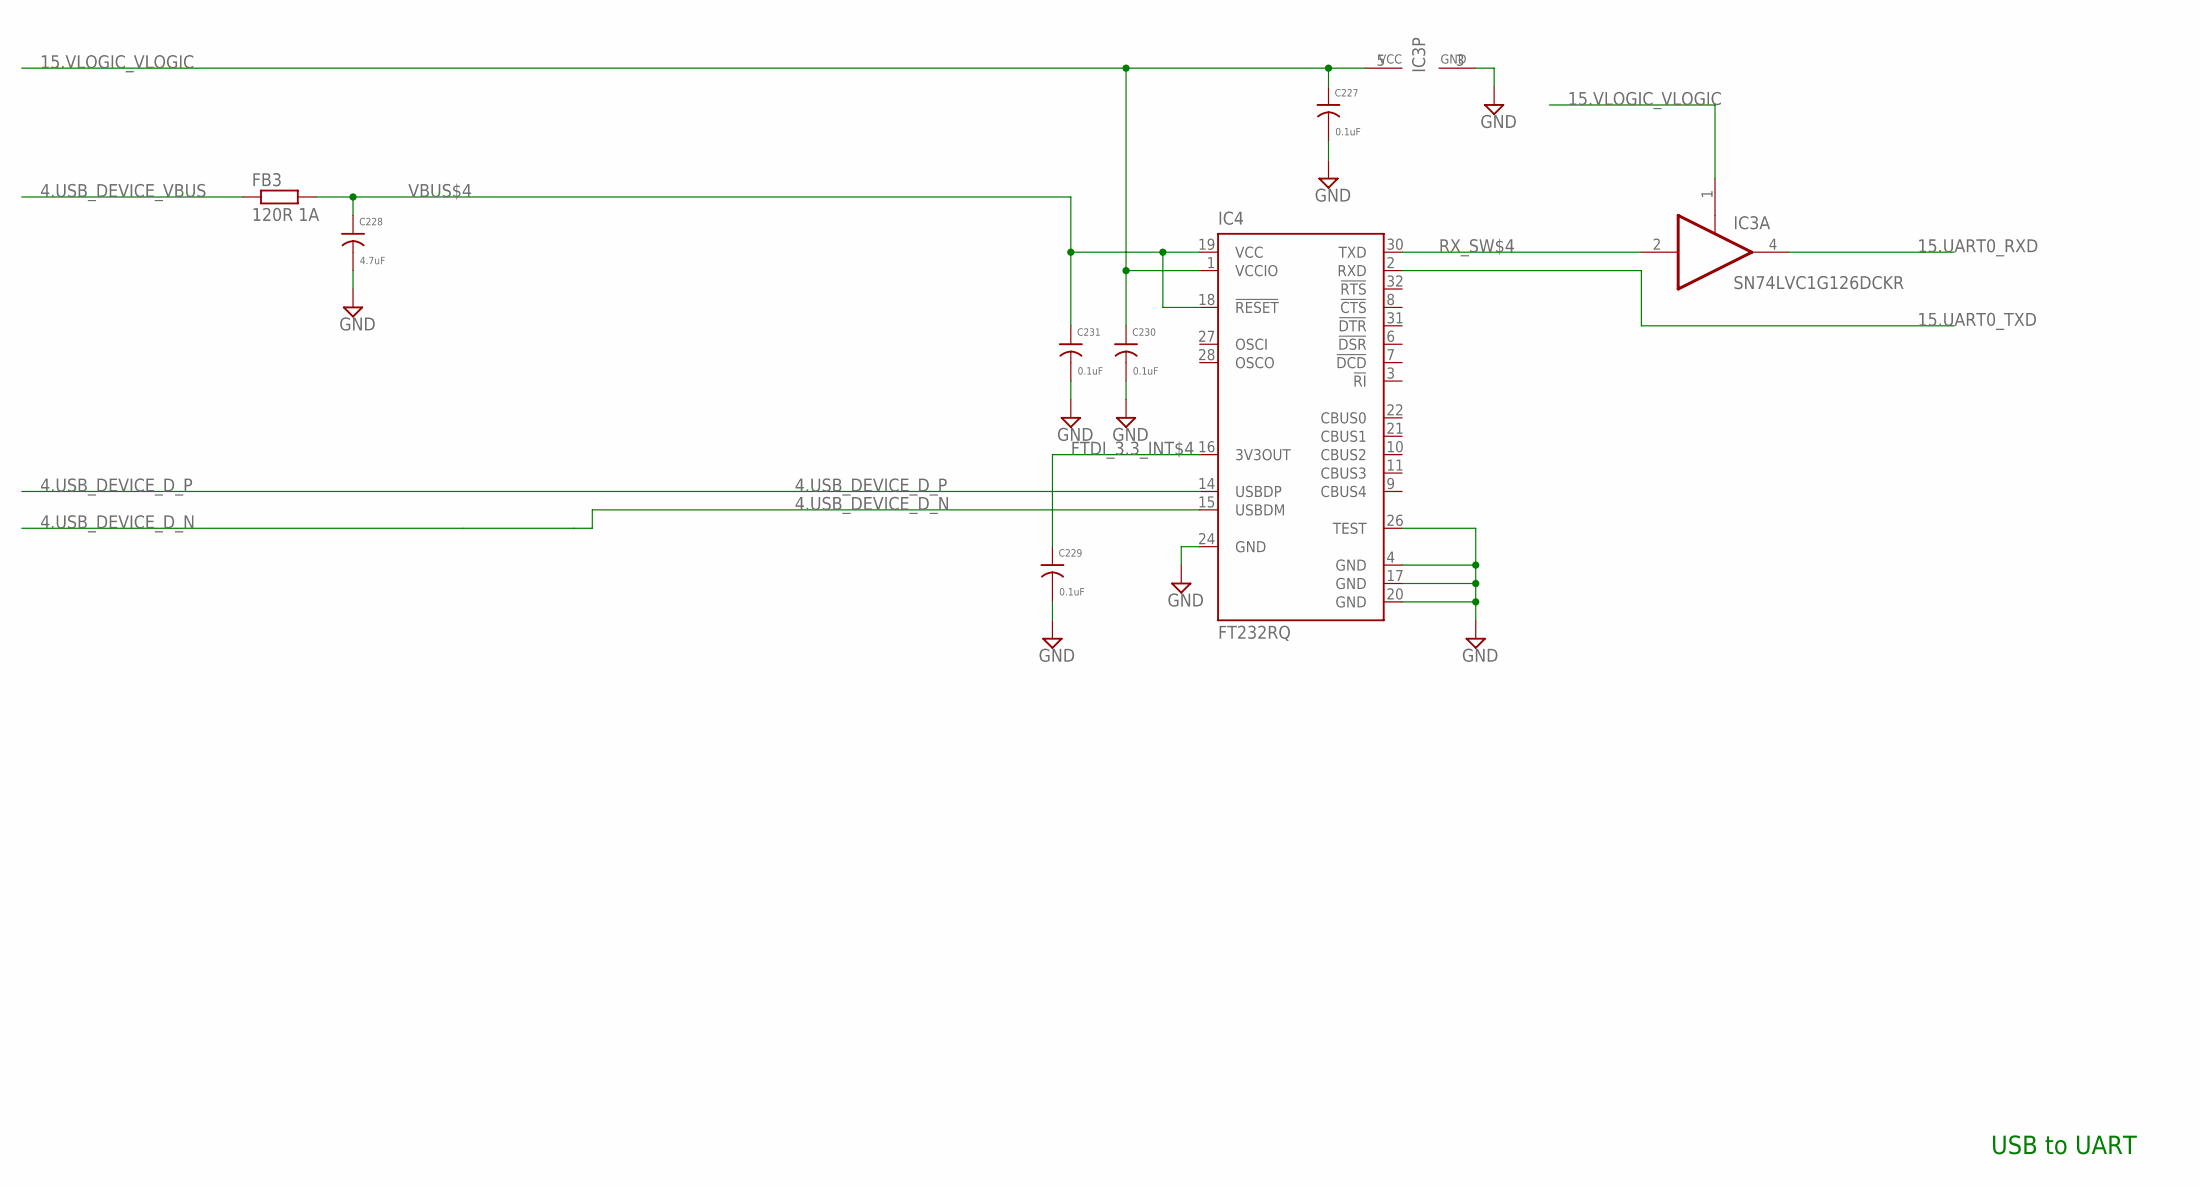
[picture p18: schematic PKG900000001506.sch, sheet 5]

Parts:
C227, C229, C230, C231: 0.1uF; 0201
C228: 4.7uF; 0603
FB3: 120R 1A; 0402
IC3: SN74LVC1G126DCKR; SC70-5
IC4: FT232RQ; QFN32

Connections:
4.USB_DEVICE_D_N: IC4.15 (USBDM); also elsewhere on the board
4.USB_DEVICE_D_P: IC4.14 (USBDP); also elsewhere on the board
4.USB_DEVICE_VBUS: FB3.1; also elsewhere on the board
15.UART0_RXD: IC3.4 (O); also elsewhere on the board
15.UART0_TXD: IC4.2 (RXD); also elsewhere on the board
15.VLOGIC_VLOGIC: C227.1, C230.1, IC3.1 (OE), IC3.5 (VCC), IC4.1 (VCCIO); also elsewhere on the board
FTDI_3.3_INT$4: C229.1, IC4.16 (3V3OUT)
GND: C227.2, C228.2, C229.2, C230.2, C231.2, IC3.3 (GND), IC4.4 (GND), IC4.17 (GND), IC4.20 (GND), IC4.24 (GND), IC4.26 (TEST); also elsewhere on the board
RX_SW$4: IC3.2 (I), IC4.30 (TXD)
VBUS$4: C228.1, C231.1, FB3.2, IC4.18 (!RESET), IC4.19 (VCC)

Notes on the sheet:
USB to UART

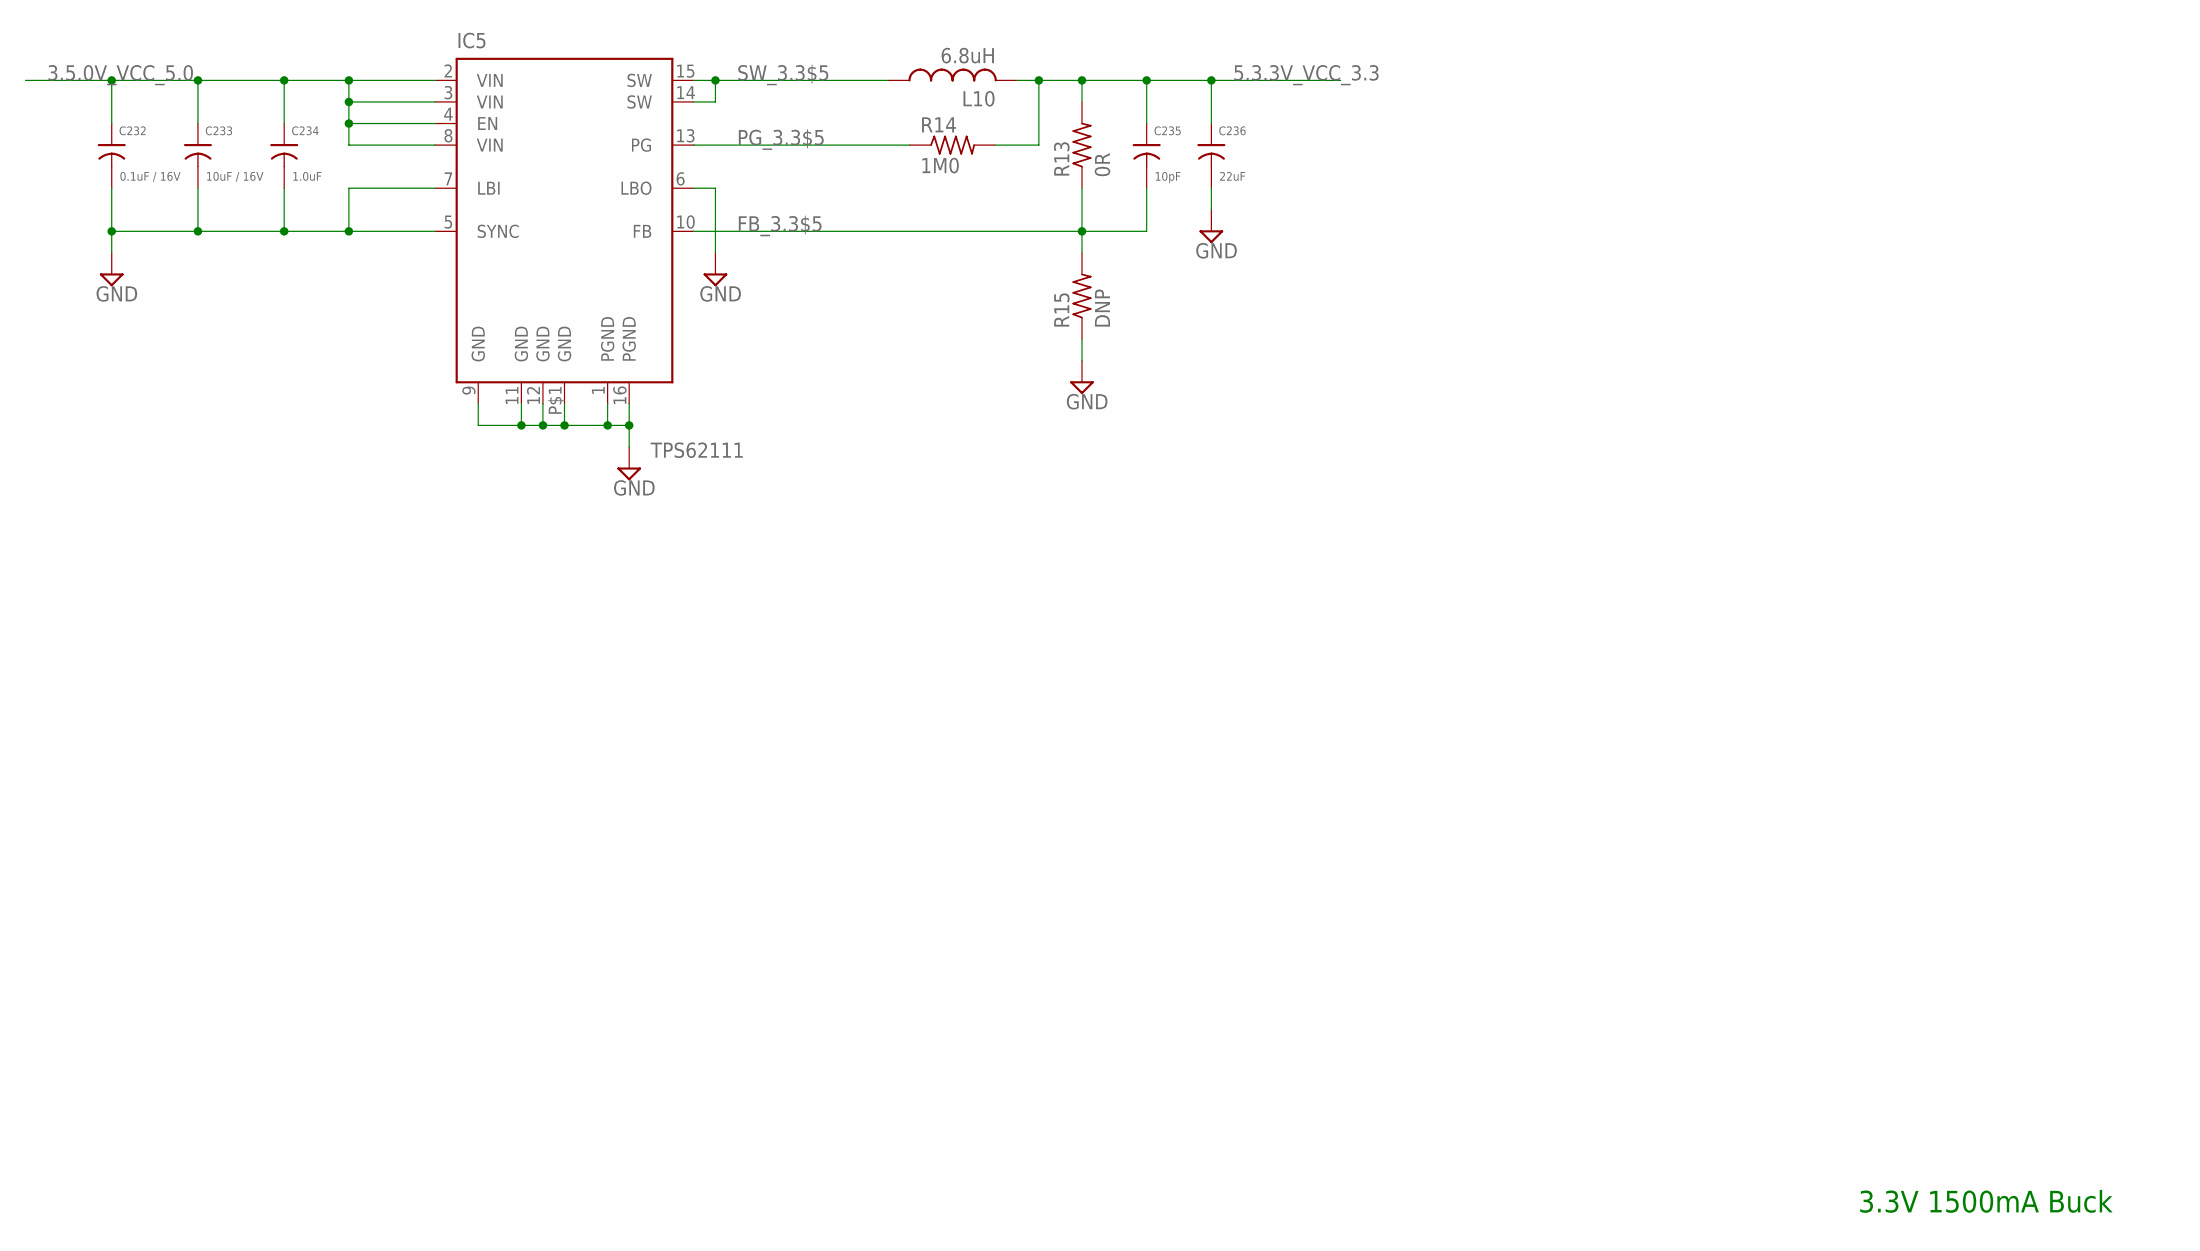
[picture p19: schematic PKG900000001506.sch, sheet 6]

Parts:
C232: 0.1uF / 16V; 0402
C233: 10uF / 16V; 0805
C234: 1.0uF; 0402
C235: 10pF; 0201
C236: 22uF; 0805
IC5: TPS62111; PQFP16
L10: 6.8uH; 1515
R13: 0R; 0402
R14: 1M0; 0201
R15: DNP; 0402

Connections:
3.5.0V_VCC_5.0: C232.1, C233.1, C234.1, IC5.2 (VIN), IC5.3 (VIN), IC5.4 (EN), IC5.8 (VIN); also elsewhere on the board
5.3.3V_VCC_3.3: C235.1, C236.1, L10.2, R13.2, R14.2; also elsewhere on the board
FB_3.3$5: C235.2, IC5.10 (FB), R13.1, R15.2
GND: C232.2, C233.2, C234.2, C236.2, IC5.1 (PGND), IC5.5 (SYNC), IC5.6 (LBO), IC5.7 (LBI), IC5.9 (GND), IC5.11 (GND), IC5.12 (GND), IC5.16 (PGND), IC5.P$1 (GND), R15.1; also elsewhere on the board
PG_3.3$5: IC5.13 (PG), R14.1
SW_3.3$5: IC5.14 (SW), IC5.15 (SW), L10.1

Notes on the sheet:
3.3V 1500mA Buck

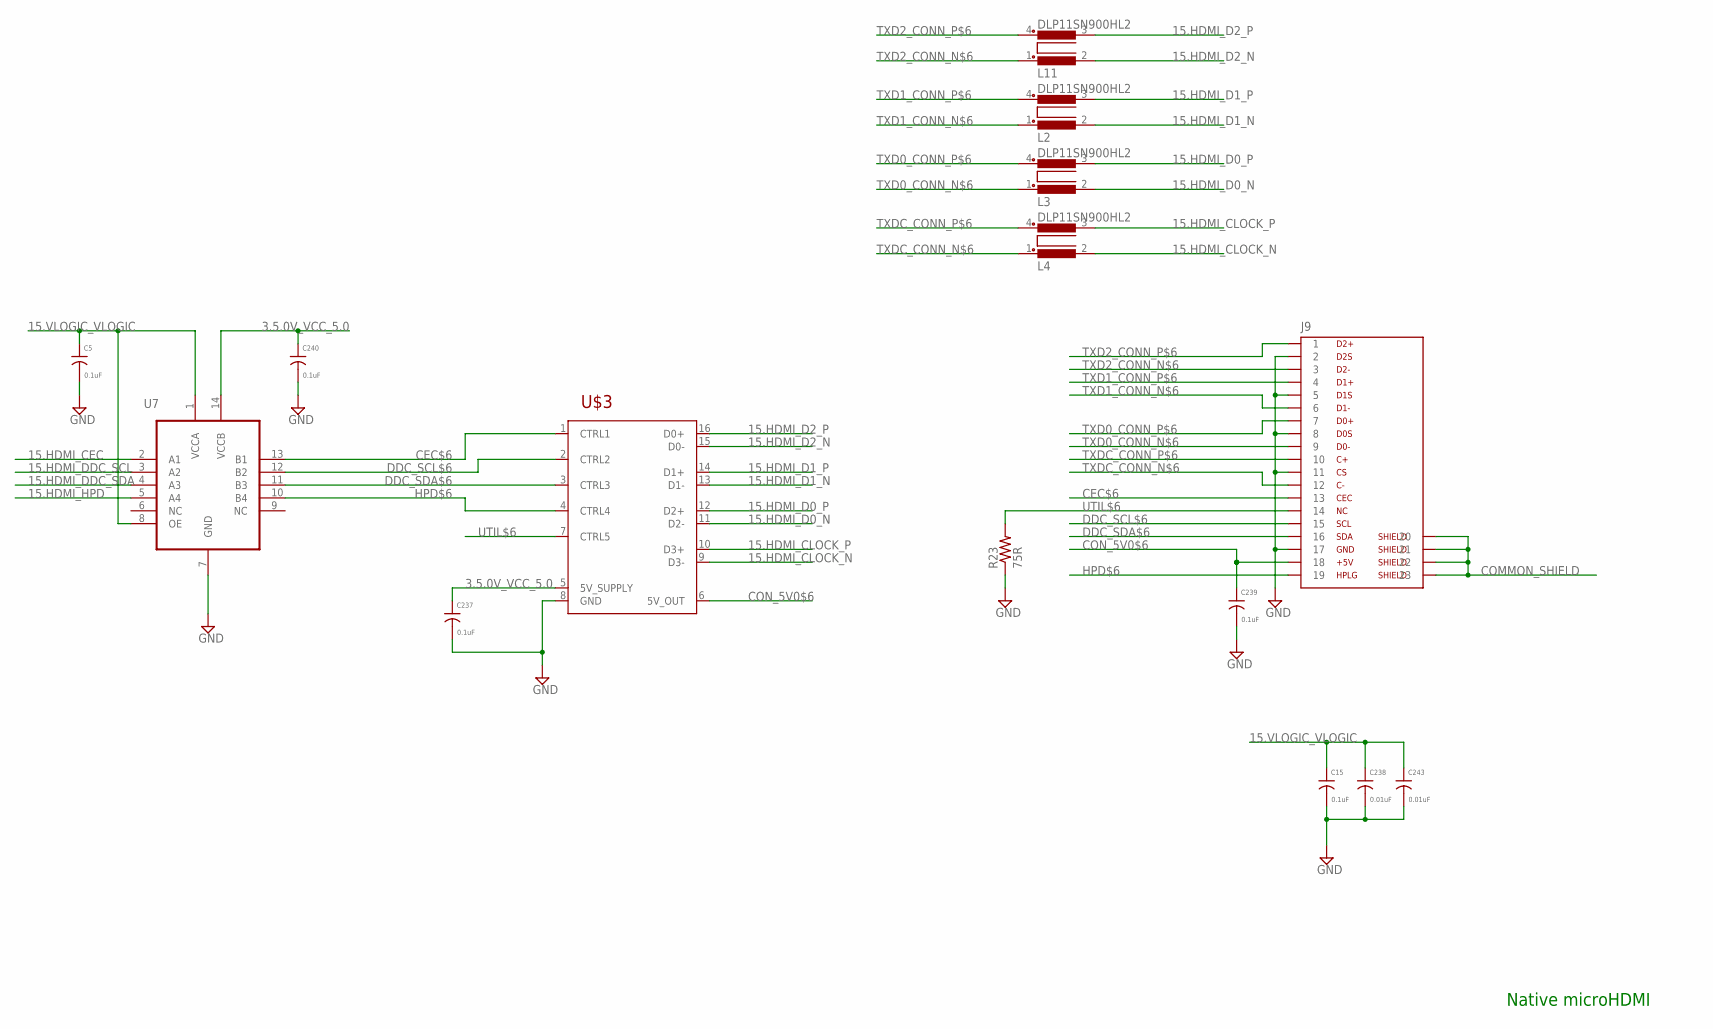
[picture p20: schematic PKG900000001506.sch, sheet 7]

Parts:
C5, C15, C237, C239, C240: 0.1uF; 0201
C238, C243: 0.01uF; 0201
J9: HDMIMICRO; 46765-001
L2, L3, L4, L11: DLP11SN900HL2; 0504-DLP11S
R23: 75R; 0402
U7: TXS0104E; S-PVQFN-N14
U$3: TPD13S523TSSOP; TSSOP16

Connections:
3.5.0V_VCC_5.0: C237.1, C240.1, U7.14 (VCCB), U$3.5 (5V_SUPPLY); also elsewhere on the board
15.HDMI_CEC: U7.2 (A1); also elsewhere on the board
15.HDMI_CLOCK_N: L4.2, U$3.9 (D3-); also elsewhere on the board
15.HDMI_CLOCK_P: L4.3, U$3.10 (D3+); also elsewhere on the board
15.HDMI_D0_N: L3.2, U$3.11 (D2-); also elsewhere on the board
15.HDMI_D0_P: L3.3, U$3.12 (D2+); also elsewhere on the board
15.HDMI_D1_N: L2.2, U$3.13 (D1-); also elsewhere on the board
15.HDMI_D1_P: L2.3, U$3.14 (D1+); also elsewhere on the board
15.HDMI_D2_N: L11.2, U$3.15 (D0-); also elsewhere on the board
15.HDMI_D2_P: L11.3, U$3.16 (D0+); also elsewhere on the board
15.HDMI_DDC_SCL: U7.3 (A2); also elsewhere on the board
15.HDMI_DDC_SDA: U7.4 (A3); also elsewhere on the board
15.HDMI_HPD: U7.5 (A4); also elsewhere on the board
15.VLOGIC_VLOGIC: C5.1, C15.1, C238.1, C243.1, U7.1 (VCCA), U7.8 (OE); also elsewhere on the board
CEC$6: J9.15 (13), U7.13 (B1), U$3.1 (CTRL1)
COMMON_SHIELD: J9.CON1 (20), J9.CON2 (21), J9.CON3 (22), J9.CON4 (23); also elsewhere on the board
CON_5V0$6: C239.1, J9.19 (18), U$3.6 (5V_OUT)
DDC_SCL$6: J9.17 (15), U7.12 (B2), U$3.2 (CTRL2)
DDC_SDA$6: J9.18 (16), U7.11 (B3), U$3.3 (CTRL3)
GND: C5.2, C15.2, C237.2, C238.2, C239.2, C240.2, C243.2, J9.4 (2), J9.7 (5), J9.10 (8), J9.13 (11), J9.16 (17), R23.1, U7.7 (GND), U$3.8 (GND); also elsewhere on the board
HPD$6: J9.1 (19), U7.10 (B4), U$3.4 (CTRL4)
TXD0_CONN_N$6: J9.11 (9), L3.1
TXD0_CONN_P$6: J9.9 (7), L3.4
TXD1_CONN_N$6: J9.8 (6), L2.1
TXD1_CONN_P$6: J9.6 (4), L2.4
TXD2_CONN_N$6: J9.5 (3), L11.1
TXD2_CONN_P$6: J9.3 (1), L11.4
TXDC_CONN_N$6: J9.14 (12), L4.1
TXDC_CONN_P$6: J9.12 (10), L4.4
UTIL$6: J9.2 (14), R23.2, U$3.7 (CTRL5)

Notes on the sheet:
Native microHDMI

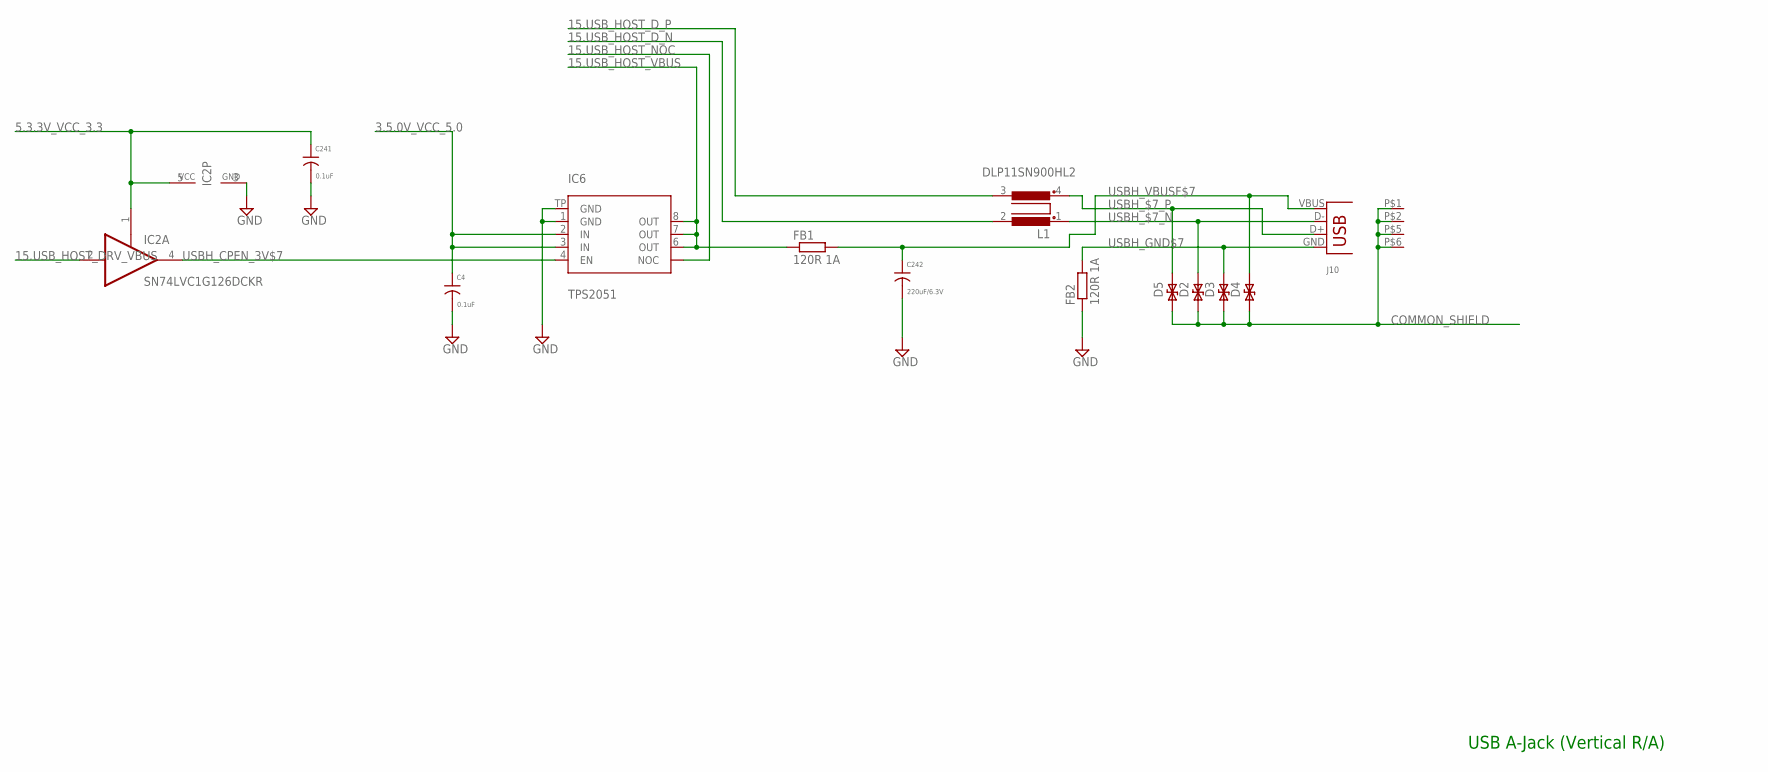
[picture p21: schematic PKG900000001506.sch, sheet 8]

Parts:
C4, C241: 0.1uF; 0201
C242: 220uF/6.3V; 1206
D2, D5: PS04LTVA1; D0402
D3, D4: B72590D50A060; D0402
FB1, FB2: 120R 1A; 0402
IC2: SN74LVC1G126DCKR; SC70-5
IC6: TPS2051; MSOP8-PAD
J10: USB-A-H-RA
L1: DLP11SN900HL2; 0504-DLP11S

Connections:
3.5.0V_VCC_5.0: C4.1, IC6.2 (IN), IC6.3 (IN); also elsewhere on the board
5.3.3V_VCC_3.3: C241.1, IC2.1 (OE), IC2.5 (VCC); also elsewhere on the board
15.USB_HOST_DRV_VBUS: IC2.2 (I); also elsewhere on the board
15.USB_HOST_D_N: L1.2; also elsewhere on the board
15.USB_HOST_D_P: L1.3; also elsewhere on the board
15.USB_HOST_NOC: IC6.5 (NOC)
15.USB_HOST_VBUS: FB1.1, IC6.6 (OUT), IC6.7 (OUT), IC6.8 (OUT)
COMMON_SHIELD: D2.P1, D3.P1, D4.P1, D5.P1, J10.P$1 (P1), J10.P$2 (P2), J10.P$5 (P3), J10.P$6 (P4); also elsewhere on the board
GND: C4.2, C241.2, C242.2, FB2.1, IC2.3 (GND), IC6.1 (GND), IC6.TP (GND); also elsewhere on the board
USBH_$7_N: D2.P2, J10.D-, L1.1
USBH_$7_P: D5.P2, J10.D+, L1.4
USBH_CPEN_3V$7: IC2.4 (O), IC6.4 (EN)
USBH_GND$7: D3.P2, FB2.2, J10.GND
USBH_VBUSF$7: C242.1, D4.P2, FB1.2, J10.VBUS

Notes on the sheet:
USB A-Jack (Vertical R/A)

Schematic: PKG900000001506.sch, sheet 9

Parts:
D6: GREEN; D0603
Q2: BSS138; SOT23
R24: 100K 1%; 0201
R25: 1K; 0201
R27: 600R; 0402

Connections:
5.3.3V_VCC_3.3: R27.2; also elsewhere on the board
15.SYS_EN_SYSEN: R24.2, R25.1; also elsewhere on the board
ANODE$11: D6.A, R27.1
GATE$11: Q2.1 (G), R25.2
GND: Q2.2 (S), R24.1; also elsewhere on the board
LED-$11: D6.C, Q2.3 (D)

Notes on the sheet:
LED

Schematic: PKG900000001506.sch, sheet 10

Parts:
J11: FPC-15VERT; 1-1734248-5
R16, R31: 1K5; 0201

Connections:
5.3.3V_VCC_3.3: J11.1_14 (14), J11.1_15 (15), R16.2, R31.2; also elsewhere on the board
15.DSI1_C_N: J11.1_5 (5); also elsewhere on the board
15.DSI1_C_P: J11.1_6 (6); also elsewhere on the board
15.DSI1_D1_N: J11.1_8 (8); also elsewhere on the board
15.DSI1_D1_P: J11.1_9 (9); also elsewhere on the board
15.DSI1_D2_N: J11.1_2 (2); also elsewhere on the board
15.DSI1_D2_P: J11.1_3 (3); also elsewhere on the board
15.I2C0_SCL: J11.1_11 (11), R31.1; also elsewhere on the board
15.I2C0_SDA: J11.1_12 (12), R16.1; also elsewhere on the board
GND: J11.1_1 (1), J11.1_4 (4), J11.1_7 (7), J11.1_10 (10), J11.1_13 (13); also elsewhere on the board

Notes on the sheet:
DSI Vertical Connector

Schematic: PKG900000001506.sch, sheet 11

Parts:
C3, C7: 0.1uF; 0201
J12: JST-GH-6V
R11: 10K 1%; 0201
U16, U18: TS3A5223; UQFN-10

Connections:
3.5.0V_VCC_5.0: J12.P1; also elsewhere on the board
5.3.3V_VCC_3.3: C3.1, C7.1, U16.1 (VCC), U18.1 (VCC); also elsewhere on the board
15.UART4_4W_CTS: U18.5 (NC1); also elsewhere on the board
15.UART4_4W_CTS_: J12.P4, U18.3 (COM1)
15.UART4_4W_RTS: U18.7 (NC2); also elsewhere on the board
15.UART4_4W_RTS_: J12.P5, U18.9 (COM2)
15.UART4_4W_RXD: U16.7 (NC2); also elsewhere on the board
15.UART4_4W_RXD_: J12.P3, U16.9 (COM2)
15.UART4_4W_TXD: U16.5 (NC1); also elsewhere on the board
15.UART4_4W_TXD_: J12.P2, U16.3 (COM1)
GND: C3.2, C7.2, J12.P6, R11.1, U16.6 (GND), U18.6 (GND); also elsewhere on the board
GPIO7: R11.2, U16.4 (SEL1), U16.8 (SEL2), U18.4 (SEL1), U18.8 (SEL2); also elsewhere on the board
GPIO30: U18.2 (NO1); also elsewhere on the board
GPIO31: U18.10 (NO2); also elsewhere on the board
GPIO32: U16.2 (NO1); also elsewhere on the board
GPIO33: U16.10 (NO2); also elsewhere on the board

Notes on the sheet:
JST GH 6-pin Vertical Header

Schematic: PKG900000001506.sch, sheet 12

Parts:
J1: JST-GH-4V

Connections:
3.5.0V_VCC_5.0: J1.P1; also elsewhere on the board
15.I2C1_SCL: J1.P2; also elsewhere on the board
15.I2C1_SDA: J1.P3; also elsewhere on the board
GND: J1.P4; also elsewhere on the board

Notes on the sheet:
JST GH Vertical 4-pin Header

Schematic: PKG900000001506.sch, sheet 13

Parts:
C10, C11, C12, C13: 2.2uF; 0402
C245: 0.1uF; 0201
IC1: CAT24C256YI-G; TSSOP8
Q1: BSS138; SOT23
R4: DNP; 0201
R6, R7, R8: 100K 1%; 0201
R9, R10: 1K5; 0201
R17, R20, R22: 0R; 0201
R18, R19: 10K 1%; 0201
R26: 4K7; 0201
U4: TLV751180330PDSQ; WFDFN-10
X1: DM-200P-SODIMM; DM-200P

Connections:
1V8$15: C12.1, U4.10 (OUT1), X1.183, X1.184, X1.185, X1.186
3.5.0V_VCC_5.0: C10.1, C11.1, U4.3 (EN1), U4.5 (EN2), U4.6 (IN2), U4.9 (IN1), X1.197, X1.198, X1.199, X1.200; also elsewhere on the board
3V3$15: C13.1, C245.1, IC1.8 (VCC), R8.1, R9.2, R10.2, R17.1, R18.2, U4.8 (OUT2), X1.39, X1.40, X1.41, X1.42, X1.189, X1.190, X1.191, X1.192, X1.193, X1.194
15.AUDIO_ACLKX: X1.63; also elsewhere on the board
15.AUDIO_AXR0: X1.71
15.AUDIO_AXR1: X1.69; also elsewhere on the board
15.AUDIO_FSX: X1.65; also elsewhere on the board
15.CAM0_C_N: X1.144; also elsewhere on the board
15.CAM0_C_P: X1.142; also elsewhere on the board
15.CAM0_D1_N: X1.138; also elsewhere on the board
15.CAM0_D1_P: X1.136; also elsewhere on the board
15.CAM0_D2_N: X1.150; also elsewhere on the board
15.CAM0_D2_P: X1.148; also elsewhere on the board
15.CAM1_C_N: X1.149; also elsewhere on the board
15.CAM1_C_P: X1.147; also elsewhere on the board
15.CAM1_D1_N: X1.161; also elsewhere on the board
15.CAM1_D1_P: X1.159; also elsewhere on the board
15.CAM1_D2_N: X1.155; also elsewhere on the board
15.CAM1_D2_P: X1.153; also elsewhere on the board
15.CAM1_D3_N: X1.143
15.CAM1_D3_P: X1.141
15.CAM1_D4_N: X1.137
15.CAM1_D4_P: X1.135
15.DSI1_C_N: X1.102; also elsewhere on the board
15.DSI1_C_P: X1.100; also elsewhere on the board
15.DSI1_D1_N: X1.96; also elsewhere on the board
15.DSI1_D1_P: X1.94; also elsewhere on the board
15.DSI1_D2_N: X1.120; also elsewhere on the board
15.DSI1_D2_P: X1.118; also elsewhere on the board
15.DSI1_D3_N: X1.114
15.DSI1_D3_P: X1.112
15.DSI1_D4_N: X1.108
15.DSI1_D4_P: X1.106
15.GPIO4_GPIO: X1.15; also elsewhere on the board
15.GPIO5_GPIO: X1.17; also elsewhere on the board
15.GPIO6_GPIO: X1.21; also elsewhere on the board
15.HDMI_CEC: X1.171; also elsewhere on the board
15.HDMI_CLOCK_N: X1.111; also elsewhere on the board
15.HDMI_CLOCK_P: X1.113; also elsewhere on the board
15.HDMI_D0_N: X1.117; also elsewhere on the board
15.HDMI_D0_P: X1.119; also elsewhere on the board
15.HDMI_D1_N: X1.123; also elsewhere on the board
15.HDMI_D1_P: X1.125; also elsewhere on the board
15.HDMI_D2_N: X1.129; also elsewhere on the board
15.HDMI_D2_P: X1.131; also elsewhere on the board
15.HDMI_DDC_SCL: X1.175; also elsewhere on the board
15.HDMI_DDC_SDA: X1.173; also elsewhere on the board
15.HDMI_HPD: R20.1; also elsewhere on the board
15.I2C0_SCL: X1.84; also elsewhere on the board
15.I2C0_SDA: X1.82; also elsewhere on the board
15.I2C1_SCL: IC1.6 (SCL), R10.1, X1.11; also elsewhere on the board
15.I2C1_SDA: IC1.5 (SDA), R9.1, X1.9; also elsewhere on the board
15.I2C_ID_SCL: X1.5; also elsewhere on the board
15.I2C_ID_SDA: X1.3; also elsewhere on the board
15.NRESET_NRESET: X1.177; also elsewhere on the board
15.PWM0_PWM: X1.45; also elsewhere on the board
15.SYS_EN_SYSEN: R26.1; also elsewhere on the board
15.UART0_RXD: X1.53; also elsewhere on the board
15.UART0_TXD: X1.51; also elsewhere on the board
15.UART4_4W_CTS: X1.33; also elsewhere on the board
15.UART4_4W_RTS: X1.35; also elsewhere on the board
15.UART4_4W_RXD: X1.29; also elsewhere on the board
15.UART4_4W_TXD: X1.27; also elsewhere on the board
15.USB_HOST_DRV_VBUS: R22.2; also elsewhere on the board
15.USB_HOST_D_N: X1.167; also elsewhere on the board
15.USB_HOST_D_P: X1.165; also elsewhere on the board
15.USB_HOST_OTGID: R4.2, X1.168
15.VLOGIC_VLOGIC: R17.2, R22.1, R26.2; also elsewhere on the board
!RPIBOOT$15: X1.2
A0$15: IC1.1 (A0), R8.2
A1$15: IC1.2 (A1), R7.2
A2$15: IC1.3 (A2), R6.2
GND: C10.2, C11.2, C12.2, C13.2, C245.2, IC1.4 (GND), IC1.7 (WP), Q1.2 (S), R4.1, R6.1, R7.1, R19.1, U4.2 (GND), U4.4 (GND), U4.PAD (GND), X1.1, X1.7, X1.8, X1.13, X1.14, X1.19, X1.20, X1.25, X1.26, X1.31, X1.32, X1.37, X1.38, X1.43, X1.44, X1.49, X1.50, X1.55, X1.56, X1.61, X1.62, X1.67, X1.68, X1.73, X1.74, X1.79, X1.80, X1.85, X1.86, X1.91, X1.92, X1.97, X1.98, X1.103, X1.104, X1.109, X1.110, X1.115, X1.116, X1.121, X1.122, X1.127, X1.128, X1.133, X1.134, X1.139, X1.140, X1.145, X1.146, X1.151, X1.152, X1.157, X1.158, X1.163, X1.164, X1.169, X1.170, X1.181, X1.182, X1.187, X1.188, X1.195, X1.196; also elsewhere on the board
GPIO7: X1.23; also elsewhere on the board
GPIO30: X1.34; also elsewhere on the board
GPIO31: X1.36; also elsewhere on the board
GPIO32: X1.46; also elsewhere on the board
GPIO33: X1.48; also elsewhere on the board
HDMI_HPD_N$15: Q1.3 (D), R18.1, X1.88
HPD_GATE$15: Q1.1 (G), R19.2, R20.2
PIN90$15: X1.90

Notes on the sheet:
Raspberry Pi CM4 (Vertical)
GPIOs 28-43 do not connect to BCM2711 They are connected to a TCA6416A GPIO expander Therefore they can only be used as GPIOs

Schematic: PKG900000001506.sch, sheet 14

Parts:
C2: 0.1uF; 0201
C6: 220pF; 0201
M1: SPH0645
R3: DNP; 0201
R5: 51R1; 0402
R28: 0R; 0201

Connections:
5.3.3V_VCC_3.3: C2.1, C6.1, M1.5 (VDD), R3.2; also elsewhere on the board
15.AUDIO_ACLKX: M1.4 (BCLK); also elsewhere on the board
15.AUDIO_AXR1: R5.1; also elsewhere on the board
15.AUDIO_FSX: M1.1 (WS); also elsewhere on the board
GND: C2.2, C6.2, M1.3 (GND), R28.1; also elsewhere on the board
SDI$16: M1.6 (DATA_OUT), R5.2
SELECT$16: M1.2 (SELECT), R3.1, R28.2

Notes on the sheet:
Knowles SPH0645 MEMS MIC.

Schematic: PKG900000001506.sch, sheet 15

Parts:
C247: 47pF; 0201
D7: B72590D50A060; D0402
R29: 10K 1%; 0201
R30: 150R; 0201
S3: EVQ

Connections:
15.NRESET_NRESET: C247.1, R30.2; also elsewhere on the board
15.VLOGIC_VLOGIC: R29.2; also elsewhere on the board
BTN_A$17: D7.P2, R29.1, R30.1, S3.B@2 (B')
GND: C247.2, D7.P1, S3.A@1 (A); also elsewhere on the board

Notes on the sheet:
Pushbutton

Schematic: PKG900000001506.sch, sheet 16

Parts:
U8: WS2812B-Mini-V3; WS2812B-MINI

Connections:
3.5.0V_VCC_5.0: U8.1 (VDD); also elsewhere on the board
19.DATA_OUT_DATA: U8.4 (DIN); also elsewhere on the board
DATA_OUT: U8.2 (DOUT)
GND: U8.3 (VSS); also elsewhere on the board

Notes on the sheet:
Top-side RGB LED (3535)

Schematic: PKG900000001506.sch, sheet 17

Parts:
U1: WS2812B-Mini-V3; WS2812B-MINI

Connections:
3.5.0V_VCC_5.0: U1.1 (VDD); also elsewhere on the board
15.PWM0_PWM: U1.4 (DIN); also elsewhere on the board
19.DATA_OUT_DATA: U1.2 (DOUT); also elsewhere on the board
GND: U1.3 (VSS); also elsewhere on the board

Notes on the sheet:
Top-side RGB LED (3535)

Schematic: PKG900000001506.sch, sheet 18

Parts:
C1: 47pF; 0201
D1: B72590D50A060; D0402
R1: 10K 1%; 0201
R2: 150R; 0201
S1: EVQ

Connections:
15.GPIO6_GPIO: C1.1, R2.2; also elsewhere on the board
15.VLOGIC_VLOGIC: R1.2; also elsewhere on the board
BTN_A$20: D1.P2, R1.1, R2.1, S1.B@2 (B')
GND: C1.2, D1.P1, S1.A@1 (A); also elsewhere on the board

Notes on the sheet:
Pushbutton

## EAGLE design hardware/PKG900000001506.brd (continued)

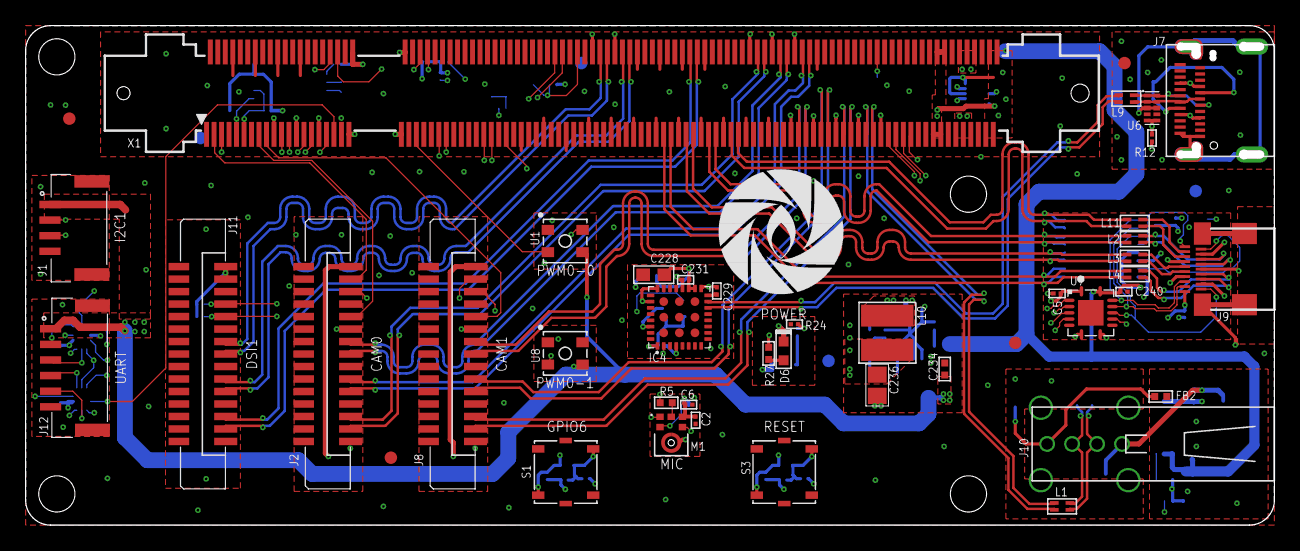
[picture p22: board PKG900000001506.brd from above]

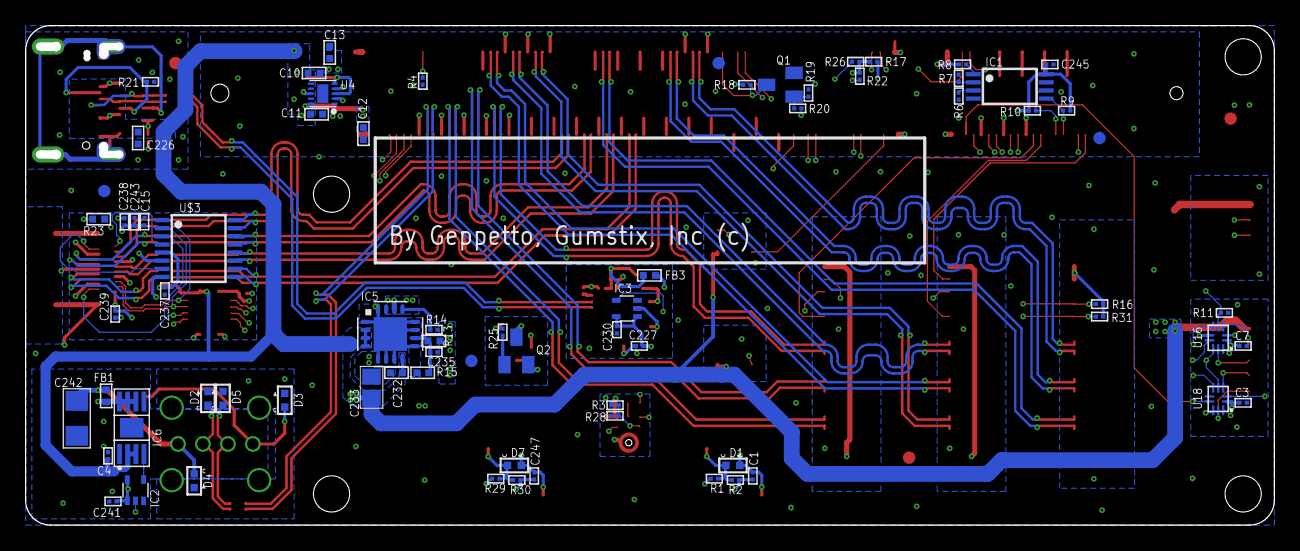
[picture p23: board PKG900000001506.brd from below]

Board: 6 copper layers, 100.0 x 40.0 mm, 122 parts (74 on the bottom side), 116 nets.

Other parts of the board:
U$1, U$41, U$43, U$45: DNP; GEPPETTO_HOLE_2.9

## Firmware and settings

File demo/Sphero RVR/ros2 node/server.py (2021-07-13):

""" 
This project is owned by Altium, and is licensed under a Creative Commons Attribution 4.0 International License.
- Software can be modified, used commercially, and distributed.
- Software can be modified and used in private.
- A license and copyright notice must be included in the software.
- Software authors provide no warranty with the software and are not liable for anything.
For any question/concerns regarding the work please contact Harnoor Singh at harnoor343@gmail.com
"""
import os
import sys
import asyncio
from sphero_sdk import SpheroRvrAsync
from sphero_sdk import SerialAsyncDal
from sphero_sdk import RvrStreamingServices
from sphero_sdk import Colors
from sphero_sdk import RvrLedGroups
import rclpy
from rclpy.node import Node
from std_msgs.msg import String, Int8MultiArray
from std_msgs.msg import Float32MultiArray
import time
import json

debug = False
delay = 250
size = 31 

# sensor variable initialization
imu_global = {}
color_global = {}
accelerometer_global = {}
ambient_global = {}
encoder_global = {}

received = 0x00     # received byte - fully received at 0x1f

class MinimalPublisher(Node):
    def __init__(self):
        super().__init__('sphero_node')
        self.publisher_ = self.create_publisher(
            String,
            'sensors',  # publish to chatter channel
            10)
        ## REMOVE
        self.remove_IMU_sub = self.create_subscription(
            Int8MultiArray,
            'remove_IMU',
            self.remove_IMU,
            10)
        self.remove_accelerometer_sub = self.create_subscription(
            Int8MultiArray,
            'remove_accelerometer',
            self.remove_accelerometer,
            10)
        self.remove_color_detection_sub = self.create_subscription(
            Int8MultiArray,
            'remove_color_detection',
            self.remove_color_detection,
            10)
        self.remove_ambient_light_sub = self.create_subscription(
            Int8MultiArray,
            'remove_ambient_light',
            self.remove_ambient_light,
            10)
        self.remove_encoders_sub = self.create_subscription(
            Int8MultiArray,
            'remove_encoders',
            self.remove_encoders,
            10)
        ## ADD
        self.add_IMU = self.create_subscription(
            Int8MultiArray,
            'subscribe_IMU',
            self.subscribe_IMU,
            10)
        self.add_accelerometer = self.create_subscription(
            Int8MultiArray,
            'subscribee_accelerometer',
            self.subscribe_accelerometer,
            10)
        self.add_color_detection = self.create_subscription(
            Int8MultiArray,
            'subscribe_color_detection',
            self.subscribe_color_detection,
            10)
        self.add_ambient_light = self.create_subscription(
            Int8MultiArray,
            'subscribe_ambient_light',
            self.subscribe_IMU,
            10)
        self.add_encoders = self.create_subscription(
            Int8MultiArray,
            'subscribe_encoders',
            self.subscribe_IMU,
            10)
        self.change_delay = self.create_subscription(
            Int8MultiArray,
            'update_delay',
            self.update_delay,
            10)
        self.drive_si = self.create_subscription(
            Float32MultiArray,
            'drive_tank_si',   
            self.drive_tank_si_callback,
            10)
        self.drive_raw = self.create_subscription(
            Float32MultiArray,
            'drive_tank_raw',   
            self.drive_tank_raw_callback,
            10)
        self.update_leds = self.create_subscription(
            Float32MultiArray,
            'change_leds',   
            self.set_leds,
            10)
        self.remove_IMU_sub 
        self.remove_accelerometer_sub
        self.remove_color_detection_sub
        self.remove_ambient_light_sub
        self.remove_encoders_sub
        self.add_IMU
        self.add_accelerometer
        self.add_color_detection
        self.add_ambient_light
        self.add_encoders
        self.change_delay
        self.drive_si
        self.drive_raw
        self.update_leds

    async def set_leds(self, msg):
        self.get_logger().info('I heard: "%s"' % msg.data)
        if debug: print("heard")
        led_data = msg.data
        R = int(led_data[0])
        G = int(led_data[1])
        B = int(led_data[2])
        await rvr.set_all_leds(
            led_group=RvrLedGroups.all_lights.value,
            led_brightness_values=[color for x in range(10) for color in [R, G, B]]
        )

    async def drive_tank_raw_callback(self, msg):
        self.get_logger().info('I heard: "%s"' % msg.data)
        if debug: print("heard")
        drive_data = msg.data
        right_drive = int(drive_data[1])
        left_drive = int(drive_data[0])
        direction = int(drive_data[2])

        if direction == 1:
            await rvr.raw_motors(
            left_mode=RawMotorModesEnum.reverse.value,
            left_duty_cycle=left_drive,  # Valid duty cycle range is 0-255
            right_mode=RawMotorModesEnum.reverse.value,
            right_duty_cycle=right_drive # Valid duty cycle range is 0-255
            )
        elif direction == 2:
            await rvr.raw_motors(
            left_mode=RawMotorModesEnum.reverse.value,
            left_duty_cycle=left_drive,  # Valid duty cycle range is 0-255
            right_mode=RawMotorModesEnum.forward.value,
            right_duty_cycle=right_drive # Valid duty cycle range is 0-255
            )   
        elif direction == 3:
            await rvr.raw_motors(
            left_mode=RawMotorModesEnum.forward.value,
            left_duty_cycle=left_drive,  # Valid duty cycle range is 0-255
            right_mode=RawMotorModesEnum.reverse.value,
            right_duty_cycle=right_drive # Valid duty cycle range is 0-255
            )  
        else:
            await rvr.raw_motors(
            left_mode=RawMotorModesEnum.forward.value,
            left_duty_cycle=left_drive,  # Valid duty cycle range is 0-255
            right_mode=RawMotorModesEnum.forward.value,
            right_duty_cycle=right_drive # Valid duty cycle range is 0-255
            )
    async def drive_tank_si_callback(self, msg):
        self.get_logger().info('I heard: "%s"' % msg.data)
        if debug: print("heard")
        drive_data = msg.data
        right_drive = drive_data[1]
        left_drive = drive_data[0]
        if right_drive > 1.55:
            right_drive = 1.55
        elif right_drive < -1.55:
            right_drive = -1.55
        
        if left_drive > 1.55:
            left_drive = 1.55
        elif left_drive < -1.55:
            left_drive = -1.55

        await rvr.drive_tank_si_units(
            left_velocity = left_drive,  # Valid velocity values are [-1.555..1.555]
            right_velocity = right_drive
        )
    
    def send(self, message):
        msg = String()
        msg.data = message
        self.publisher_.publish(msg)
        if debug: self.get_logger().info('Publishing: "%s"' % msg.data)
    
    def update_delay(self, msg):
        if debug: print("heard")
        data = msg.data
        global delay
        if data[0] < 40:
            delay = 40
        else: 
            delay = data[0]
        additionalVar  = data[1]
        if debug: print('delay rated updated to :', data[0])
   
    async def remove_IMU(self, msg):
        global delay
        global imu_global
        data = msg.data
        await rvr.sensor_control.stop()
        await rvr.sensor_control.remove_sensor_data_handler(service=RvrStreamingServices.imu)
        imu_global = {}
        await rvr.sensor_control.start(interval=delay)
        
   
    async def subscribe_IMU(self, msg):
        global delay
        global imu_global
        data = msg.data
        await rvr.sensor_control.stop()
        await rvr.sensor_control.add_sensor_data_handler(
            service=RvrStreamingServices.imu,
            handler=imu_handler
        )
        await rvr.sensor_control.start(interval=delay)

    async def remove_accelerometer(self, msg):
        global delay
        global accelerometer_global
        data = msg.data
        await rvr.sensor_control.stop()
        await rvr.sensor_control.remove_sensor_data_handler(service=RvrStreamingServices.accelerometer)
        accelerometer_global = {}
        await rvr.sensor_control.start(interval=delay)
        
   
    async def subscribe_accelerometer(self, msg):
        global delay
        data = msg.data
        await rvr.sensor_control.stop()
        await rvr.sensor_control.add_sensor_data_handler(
        service=RvrStreamingServices.accelerometer,
        handler=accelerometer_handler
        )
        await rvr.sensor_control.start(interval=delay)
    
    async def remove_color_detection(self, msg):
        global delay
        global color_global
        data = msg.data
        await rvr.sensor_control.stop()
        await rvr.sensor_control.remove_sensor_data_handler(service=RvrStreamingServices.color_detection)
        color_global = {}
        await rvr.sensor_control.start(interval=delay)
        
    async def subscribe_color_detection(self, msg):
        global delay
        data = msg.data
        await rvr.sensor_control.stop()
        await rvr.enable_color_detection(is_enabled=True)
        if debug: print("Starting color handler")
        await rvr.sensor_control.add_sensor_data_handler(
            service=RvrStreamingServices.color_detection,
            handler=color_detected_handler
          )
        await rvr.sensor_control.start(interval=delay)

    async def remove_ambient_light(self, msg):
        global delay
        global ambient_global
        data = msg.data
        await rvr.sensor_control.stop()
        await rvr.sensor_control.remove_sensor_data_handler(service=RvrStreamingServices.ambient_light)
        ambient_global = {}
        await rvr.sensor_control.start(interval=delay)
        
    async def subscribe_ambient_light(self, msg):
        global delay
        data = msg.data
        await rvr.sensor_control.stop()
        await rvr.sensor_control.add_sensor_data_handler(
            service=RvrStreamingServices.ambient_light,
            handler=ambient_light_handler
        )
        await rvr.sensor_control.start(interval=delay)

    async def remove_encoders(self, msg):
        global delay
        global encoder_global
        data = msg.data
        await rvr.sensor_control.stop()
        await rvr.sensor_control.remove_sensor_data_handler(service=RvrStreamingServices.encoders)
        encoder_global = {}
        await rvr.sensor_control.start(interval=delay)
        
    async def subscribe_encoders(self, msg):
        global delay
        data = msg.data
        await rvr.sensor_control.stop()
        await rvr.sensor_control.add_sensor_data_handler(
            service=RvrStreamingServices.encoders,
            handler=encoder_handler
        )
        await rvr.sensor_control.start(interval=delay)
# Check and send all values are collected
def checkData():
    publisher.send(
        json.dumps({
                **imu_global,
                **color_global,
                **accelerometer_global,
                **ambient_global,
                **encoder_global
        })
    )
    if debug: print("spinning")
    rclpy.spin_once(publisher, timeout_sec=0.01)
    if debug: print('publish')

def clear_buffer():
    global imu_global
    global color_global
    global accelerometer_global
    global ambient_global
    global encoder_global
    imu_global = {}
    color_global = {}
    accelerometer_global = {}
    ambient_global = {}
    encoder_global = {}

async def imu_handler(imu_data):
    if debug: print('IMU data received')
    global imu_global
    global received
    imu_global = imu_data
    received = received | (1)
    checkData()
    clear_buffer()

async def color_detected_handler(color_detected_data):
    #print('Color detection data response: ', color_detected_data)
    if debug: print('Color detection data received')
    global color_global
    global received
    color_global = color_detected_data
    received = received | (1 << 1)
    checkData()
    clear_buffer()
async def accelerometer_handler(accelerometer_data):
    if debug: print('Accelerometer data received')
    global accelerometer_global
    global received
    accelerometer_global = accelerometer_data
    received = received | (1 << 2)
    checkData()
    clear_buffer()
async def ambient_light_handler(ambient_light_data):
    if debug: print('Ambient light data received')
    global ambient_global
    global received
    ambient_global = ambient_light_data
    received = received | (1 << 3)
    checkData()
    clear_buffer()
async def encoder_handler(encoder_data):
    if debug: print('Encoder data received')
    global encoder_global
    global received
    encoder_global = encoder_data
    received = received | (1 << 4)
    checkData()
    clear_buffer()

rclpy.init(args=None)
publisher = MinimalPublisher()

async def main():
    """ This program demonstrates how to enable multiple sensors to stream."""
    await rvr.wake()
    # Give RVR time to wake up
    await asyncio.sleep(2)
    await rvr.set_all_leds(
        led_group=RvrLedGroups.all_lights.value,
        led_brightness_values=[color for x in range(10) for color in [0, 255, 0]]
    )
    await rvr.sensor_control.stop()
    if debug: print("Starting imu handler")
    await rvr.sensor_control.add_sensor_data_handler(
        service=RvrStreamingServices.imu,
        handler=imu_handler
    )
    await rvr.enable_color_detection(is_enabled=True)
    if debug: print("Starting color handler")
    await rvr.sensor_control.add_sensor_data_handler(
        service=RvrStreamingServices.color_detection,
        handler=color_detected_handler
    )
    if debug: print("Starting accelerometer handler")
    await rvr.sensor_control.add_sensor_data_handler(
        service=RvrStreamingServices.accelerometer,
        handler=accelerometer_handler
    )
    if debug: print("Starting ambient light handler")
    await rvr.sensor_control.add_sensor_data_handler(
        service=RvrStreamingServices.ambient_light,
        handler=ambient_light_handler
    )
    if debug: print("Starting encoder handler")
    await rvr.sensor_control.add_sensor_data_handler(
        service=RvrStreamingServices.encoders,
        handler=encoder_handler
    )
    if debug: print("Starting sensor control")
    global delay
    await rvr.sensor_control.start(interval=delay)

if __name__ == '__main__':
    try:
        loop = asyncio.get_event_loop()
        args = sys.argv[1:]
        rvr = SpheroRvrAsync(
            dal=SerialAsyncDal(loop,port_id=args[0])
        ) 
        asyncio.ensure_future(
            main()
        )
        loop.run_forever()

    except KeyboardInterrupt:
        print('\nProgram terminated with keyboard interrupt.')

        loop.run_until_complete(
            asyncio.gather(
                rvr.sensor_control.clear(),
                rvr.close()
            )
        )

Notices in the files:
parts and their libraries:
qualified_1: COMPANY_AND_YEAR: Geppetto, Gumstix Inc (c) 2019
